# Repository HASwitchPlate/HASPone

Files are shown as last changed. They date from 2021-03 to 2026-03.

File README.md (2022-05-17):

# HA SwitchPlate HASPone

The HASPone is a DIY touchscreen controller you can mount into a [standard North American work box](https://archive.org/details/NEMA-WD-6-2016).  It connects to your home automation system over Wifi+MQTT to display useful information and to control your smart devices.  The result is an attractive and highly-customizable home controller you can build yourself!

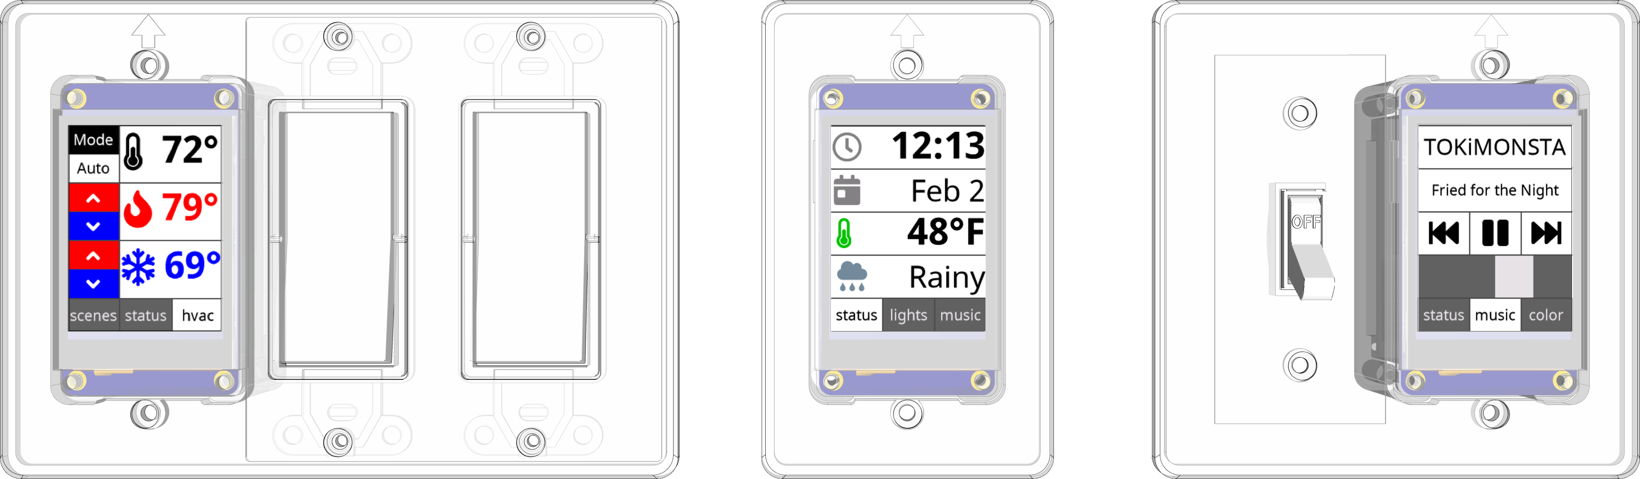
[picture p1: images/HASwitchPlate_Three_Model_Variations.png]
HA SwitchPlate Models


## Demo screens

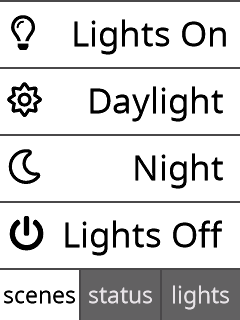
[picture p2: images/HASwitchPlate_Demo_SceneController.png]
Scene controller
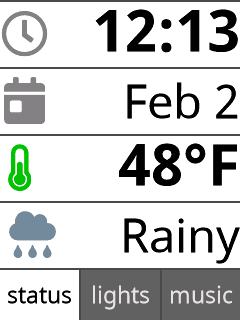
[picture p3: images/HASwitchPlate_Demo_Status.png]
Status display
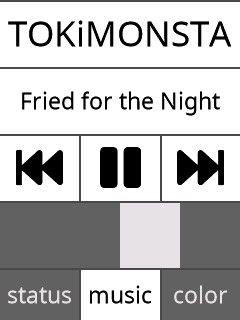
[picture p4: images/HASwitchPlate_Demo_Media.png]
Media control
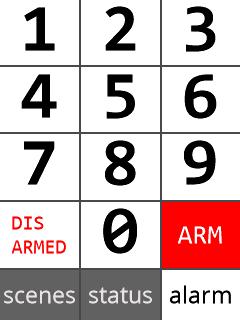
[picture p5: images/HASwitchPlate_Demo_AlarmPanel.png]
Alarm Panel
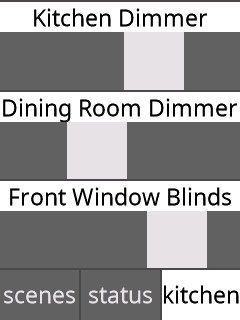
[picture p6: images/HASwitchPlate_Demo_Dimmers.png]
Slider/Dimmer Controls
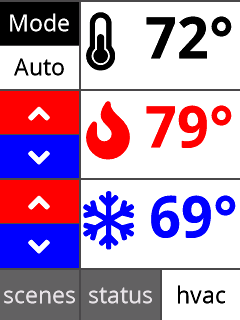
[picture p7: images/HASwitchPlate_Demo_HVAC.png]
HVAC Controls
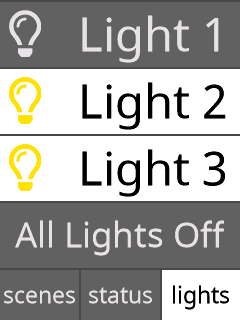
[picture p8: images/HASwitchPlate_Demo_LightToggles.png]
Light toggles
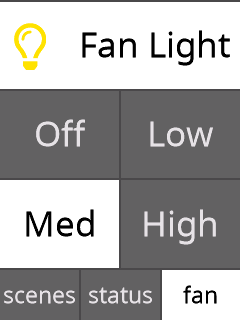
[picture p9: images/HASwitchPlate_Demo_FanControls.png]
Fan controller
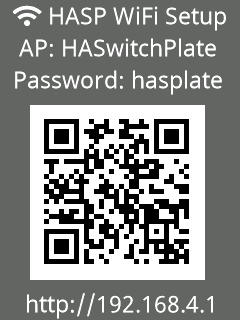
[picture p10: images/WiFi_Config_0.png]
WiFi Setup
        

## [Purchase an assembled unit](https://www.etsy.com/listing/1191709235/haspone-haswitchplate-touchscreen-home)

This build requires some specialist skills and tools. [You can buy an assembled device here](https://www.etsy.com/listing/1191709235/haspone-haswitchplate-touchscreen-home) if you want to get started without picking up a soldering iron.  [Buy the PCB here](https://www.etsy.com/listing/1177721322/haspone-pcb) if you want to safely assemble your own HASPone.

## [Build your own HASPone](https://github.com/HASwitchPlate/HASPone/wiki/Building-your-own-HASPone)

[Check out the build guide in the HASPone wiki](https://github.com/HASwitchPlate/HASPone/wiki/Building-your-own-HASPone).

## [Setup HASPone for Home Assistant](https://github.com/HASwitchPlate/HASPone/wiki/Configure-your-HASPone-for-Home-Assistant)

If you're purchased or built a HASPone, [now it's time to make it talk to Home Assistant](https://github.com/HASwitchPlate/HASPone/wiki/Configure-your-HASPone-for-Home-Assistant).

Here's a quick look at the setup process:

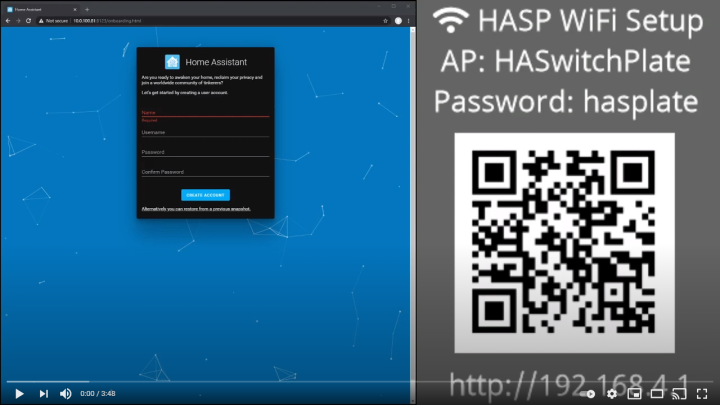
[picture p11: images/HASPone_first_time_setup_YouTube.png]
HASPone first-time setup (https://youtu.be/zi784hr69QA)


## Have a question?

Come talk to us in [the HASPone discussion forum](https://github.com/HASwitchPlate/HASPone/discussions) or [chat with us on Discord](https://haswitchplate.com/discord).

## [Buy me a coffee](https://www.buymeacoffee.com/gW5rPpsKR)

Buy me a coffee (https://www.buymeacoffee.com/gW5rPpsKR)

This project is powered by coffee.  [I might get a little weird about it at times](https://github.com/aderusha/RoastLearner), but it's not much of a stretch to suggest that coffee both powers and consumes a fair portion of my mental energy.  [Hook me up if you think HASP is cool](https://www.buymeacoffee.com/gW5rPpsKR).  Thanks!

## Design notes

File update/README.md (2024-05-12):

# HASP Auto-Update

Files here are used for the auto-update routine which will periodically check GitHub for new firmware versions.  

---

## Legacy Releases

If you need to downgrade for whatever reason, paste the link below into the "Update ESP8266 from URL" dialog under "Update Firmware".

* **HASPone 1.05** `https://raw.githubusercontent.com/HASwitchPlate/HASPone/570eefcb901c8eb40947a5fa53b8760ae21612f2/Arduino_Sketch/HASwitchPlate.ino.d1_mini.bin`
* **HASPone 1.04** `https://raw.githubusercontent.com/HASwitchPlate/HASPone/f20474d8f705f9dc08ac3c8c1d5c3de324d1e6fe/Arduino_Sketch/HASwitchPlate.ino.d1_mini.bin`
* **HASPone 1.03** `https://raw.githubusercontent.com/HASwitchPlate/HASPone/2a8df65334f8b694676e4e2d75cdc7e6daac9b4e/Arduino_Sketch/HASwitchPlate.ino.d1_mini.bin`
* **HASPone 1.02** `https://raw.githubusercontent.com/HASwitchPlate/HASPone/2098a87c3b6910992a1b425628f7b1b8735487db/Arduino_Sketch/HASwitchPlate.ino.d1_mini.bin`
* **HASPone 1.01** `https://raw.githubusercontent.com/HASwitchPlate/HASPone/a1ca2c244bc15feb0360132d86a3048908be5aa6/Arduino_Sketch/HASwitchPlate.ino.d1_mini.bin`
* **HASPone 1.00** `https://raw.githubusercontent.com/HASwitchPlate/HASPone/bdaa5e7d906666df31adba7b503f14c2e3ccaeb5/Arduino_Sketch/HASwitchPlate.ino.d1_mini.bin`

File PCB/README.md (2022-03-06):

# PCB source files and Gerber outputs

Above you'll find [KiCad](http://kicad-pcb.org/) [schematic](https://github.com/aderusha/HASwitchPlate/blob/master/PCB/HASwitchPlate.sch) and [PCB](https://github.com/aderusha/HASwitchPlate/blob/master/PCB/HASwitchPlate.kicad_pcb) files along with [a ZIP bundle containing complete gerber outputs](https://github.com/aderusha/HASwitchPlate/raw/master/PCB/HASwitchPlate.gerbers.zip) ready to send to [your favorite PCB shop](https://www.allpcb.com/?Mb_InviteId=34099).

I had these manufactured by [AllPCB](https://www.allpcb.com/?Mb_InviteId=34099) and I'm very happy with the results.  The quality has been perfect and their shipping time to the US has been under a week across several orders.  [If you sign up through this link](https://www.allpcb.com/?Mb_InviteId=34099)  they credit me some cash that I can use for future projects which helps me out a bit.

If you aren't looking to buy a zillion boards, I may have some ready for US orders in [my Etsy store](https://www.etsy.com/listing/1177721322/haspone-pcb).

HA SwitchPlate PCB

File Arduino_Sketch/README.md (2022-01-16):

# HASwitchPlate Arduino Sketch

Here you'll find the [Arduino source code](./HASwitchPlate/HASwitchPlate.ino) for the microcontroller firmware along with [a pre-compiled binary image](https://github.com/HASwitchPlate/HASPone/raw/main/Arduino_Sketch/HASwitchPlate.ino.d1_mini.bin) which can be [flashed directly to your ESP8266](https://github.com/HASwitchPlate/HASPone/wiki/Flashing-HASPone-to-an-ESP8266).

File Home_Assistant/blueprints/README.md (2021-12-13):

# HASPone Blueprint Exchange

---

## HASPone Core Functionality



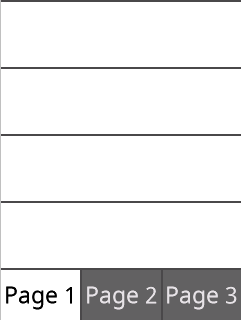
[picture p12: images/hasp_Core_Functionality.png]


This blueprint provides the basic functionality for your HASPone. Deploy one automation from this blueprint for each of your HASPone devices.

---

### Activate Page on Idle



Activates a selected page after a specified period of inactivity.

---

### Activate Page



A button on the HASPone will activate a page when pressed. Can be combined on a button with another blueprint which displays text.

---

### Create Device Triggers



Create [Device Triggers](https://www.home-assistant.io/integrations/device_trigger.mqtt/) for each of the HASPone buttons defined. Device triggers can be utilized while creating your own automations through the Home Assistant UI. This allows for the easy creation of automations which will be triggered when pressing buttons on your HASPone.

---

### Display Alarm Control on Page 7



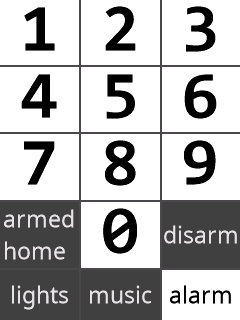
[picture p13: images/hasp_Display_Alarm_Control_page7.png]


Page 7 controls a selected alarm panel for code entry and arm/disarm.

---

### Display Calendar with Icon



Preview

A HASPone button displays month + date on the right with a calendar icon on the left.

---

### Display Clock with Icon



Preview

A HASPone button displays a clock on the right with a clock icon on the left.

---

### Display Clock



Preview

A HASPone button displays a clock with configurable text options.

---

### Display Dimmer with Icon



Preview

A HASPone button displays a dimmer control on page 4 and 5 with a toggle on/off icon to the left.

---

### Display Entity State or Attribute



Preview

A HASPone button displays the state or attribute value of an entity

---

### Display Media Controls on Page 8



Preview

Page 8 controls a selected media player with artist and track info, track back/play|pause/track forward, and volume control

---

### Display Template



Preview

A button on the HASPone will display the output of a template.  The template is updated when the state of a selected entity updates.

---

### Display Text



Preview

A button on the HASPone will display text.  This can be useful when combined with other blueprints which perform an action, but don't apply a label to a button. Deploy both blueprints on the same button, and now you have a button that says things and does things.

---

### Display Toggle



Preview

Press a button on the HASPone to toggle the state of an entity.  The button colors and text can change in response to the on/off state or attribute of the selected entity.

---

### Display Value with Icon and Colors



Preview

A HASPone button displays the current value of an entity (state or attribute) with a dynamic icon on the left and (optional) colors.  Up to 5 icons and color ranges are supported.

---

### Display Volume Control on page 8



Preview

The slider button on page 8 displays a volume control

---

### Display Weather Condition with Icon



Preview

A HASPone button displays the current weather condition on the right with a matching icon on the left

---

### Display Weather Condition Icon Only



Preview

A HASPone button displays the current weather condition as an icon

---

### Display Weather Forecast



Preview

A HASPone button displays an attribute of a selected weather forecast. You can use this to display tomorrow's condition, or tonight's low temp. Available forecast conditions will vary by weather provider, check your selected provider's state under `Developer Tools` > `States` to get a sense of what your selected provider has to offer.

---

### Display Weather Temperature with Colored Icon Only



Preview

A HASPone button displays the current temperature as an icon that is optionally coloured.

---

### Display Weather Temperature with Icon and Colors



Preview

A HASPone button displays the current temperature from a selected weather provider on the right with a dynamic thermometer icon on the left and (optional) colors.

---

### Perform Action



A button on the HASPone will perform an action when pressed. Can be combined on a button with another blueprint which displays text.

---

### Cycle Automations



Preview

A button on the HASPone will toggle through as many as 10 selected automations.  This allows the user to assign multiple blueprints to the same button on the HASPone device, and to cycle between them by pressing the selected button.

Optionally, a timeout can be set to cycle back to a "default" automation after a specified interval, or to continuously cycle through selected automations.

---

### Dim Screen with Sun



Dim the HASPone backlight in response to the sun going up and down.

---

### Dim Screen on Idle



Dim the screen backlight after a specified period of inactivity.

---

### Apply Theme



A button on the HASPone will have the current device theme or custom colors applied.

---

### HASPone Theme Dark on Light



Preview

Press RUN ACTIONS to apply the theme Dark on Light to the selected HASPone device

---

### HASPone Theme Light on Dark



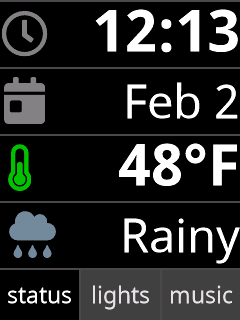
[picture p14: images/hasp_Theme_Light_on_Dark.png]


Press RUN ACTIONS to apply the theme Light on Dark to the selected HASPone device

---

### HASPone Theme Light on Dark Blue



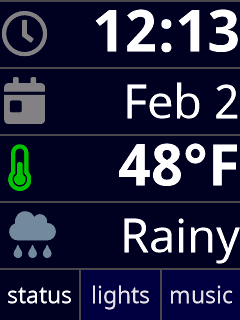
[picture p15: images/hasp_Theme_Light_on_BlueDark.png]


Press RUN ACTIONS to apply the theme Light on Dark Blue to the selected HASPone device

---

### Remove MQTT Discovery Devices



Press RUN ACTIONS to remove retained MQTT discovery messages for a decommissioned HASPone.

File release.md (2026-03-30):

# HASPone v1.09 Release Notes

## Home Assistant Update Integration

HASPone now registers as an updatable device in Home Assistant. When a firmware update is available, it appears in the HA **Settings > Updates** dashboard alongside your other device updates.

- **ESP8266 firmware** and **Nextion LCD firmware** are tracked as separate update entities
- Click **Install** directly from Home Assistant to trigger the OTA update
- Release notes link is included in each update card, configurable per-release via `version.json`
- Update availability is checked automatically every 12 hours

## Fix for breaking changes in Home Assistant MQTT entity naming

Big thanks to @SylvainGa for the 1.07 and 1.08 releases, fixing a breaking change in Home Assistant: https://github.com/HASwitchPlate/HASPone/commit/68df52da6bd4ba3a4f2c9e98dcf1b7bcd363443b

**All blueprints will need to be updated!** - make sure to copy down all files from `Home_Assistant/blueprints/*.yaml` into your Home Assistant installation.

## Bug Fixes

### Fixed Nextion ACK timeout logic

The ACK wait loops in `nextionSetAttr()` and `nextionGetAttr()` used `||` (OR) with an inverted timeout comparison, meaning they would exit immediately instead of waiting for the ACK response. Changed to `&&` (AND) with corrected comparison direction so the loop properly waits for either an ACK or a timeout.

### Fixed beep on/off state inversion

The beep feedback had on and off states swapped: `analogWrite(beepPin, 254)` was called during the "off" phase and `analogWrite(beepPin, 0)` during the "on" phase. Corrected so the beep actually sounds during the on interval.

### Fixed WiFi password display in web UI

The web configuration page checked `mqttUser` instead of `mqttPassword` when deciding whether to show the password placeholder. The MQTT password field would appear empty even when a password was saved.

### Fixed page restore after LCD reboot

`nextionReset()` and `espWifiConnect()` compared `nextionActivePage` with a truthy check, which treated page 0 as "no page set." Changed to `>= 0` so page 0 is correctly restored.

### Fixed debugPrint() brace scoping

`debugPrint()` had a misplaced opening brace that put `Serial.print(debugText)` outside the `if (debugSerialEnabled)` block, causing serial output even when debug was disabled.

## Improvements

### mDNS actually starts now

Added the missing `MDNS.begin(haspNode)` call. Without it, the mDNS service registration was configured but the responder itself was never started, so the device was not discoverable on the local network.

### mDNS now advertises MAC address and MQTT server

Added `mac` and `mqtt_server` TXT records to the mDNS service advertisement, making device identification easier on the local network.

### WiFi reconnection hardened

- `WiFi.hostname()`, `WiFi.setAutoReconnect(true)`, and `WiFi.setSleepMode(WIFI_NONE_SLEEP)` are now set on both initial connection and reconnection
- `espWifiReconnect()` uses saved credentials from WiFiManager when no hardcoded SSID is configured, instead of passing empty strings to `WiFi.begin()`
- WiFi persistence disabled during reconnection to avoid unnecessary flash writes
- All WiFi settings are reapplied after reconnection

### OTA update reliability improved

- MQTT client, TLS buffers, telnet, and web server are disconnected/stopped before starting ESP OTA to free memory
- HTTPS OTA buffer increased from 512 to 4096 bytes for more reliable downloads
- Removed manual URL parsing — `ESPhttpUpdate` handles it with `HTTPC_FORCE_FOLLOW_REDIRECTS`

### Update check rewritten for Cloudflare compatibility

`updateCheck()` was rewritten to use raw HTTP/1.0 requests with explicit content-length parsing instead of `HTTPClient`. This resolves failures when `version.json` is served behind Cloudflare's edge network.

### Firmware download URLs switched to HTTP

Default firmware URLs changed from `https://` to `http://` to reduce memory pressure during OTA downloads on the ESP8266. Previously HTTPS was used through a cloud-hosted VM which would proxy from GitHub, that now runs through CloudFlare.  While this does change from HTTPS to HTTP, the security posture doesn't change as the ESP8266 does not have the capacity to pull in and validate the full cert chain so it never did actually check any part of that in previous releases.  The update check itself still uses HTTPS.

### Debug serial output optimized

`SoftwareSerial debugSerial` is now a global instance instead of being constructed and destroyed on every `debugPrintln()` / `debugPrint()` / `debugPrintCrash()` call. Reduces heap churn during debug output.

### OTA progress display deduplicated

`nextionUpdateProgress()` now only sends display updates when the percentage actually changes, avoiding redundant serial commands to the Nextion during firmware uploads.

### PlatformIO build configuration updated

Added `monitor_speed = 115200` and `upload_speed = 921600` to `platformio.ini` for faster development iteration.

## ESPHome Example Updated

The ESPHome example configuration (`esphome/haspone.yaml`) has been updated with:

- Serial logging disabled (`baud_rate: 0`) since the UART pins conflict with the Nextion — logs are available via the web UI and ESPHome dashboard instead
- Updated `ota:` to current ESPHome syntax (`platform: esphome`)
- Detailed header comments explaining the hardware UART constraints and why SoftwareSerial is required on this PCB
- Version bumped to 0.0.2

## version.json Changes

All firmware entries now include a `release_url` field pointing to the GitHub releases page. The device reads this on each update check and passes it to Home Assistant so the update card links to the correct release notes.

## Files Changed

| File | Description |
|---|---|
| `Home_Assistant/blueprints/*.yaml` | New blueprints as of v1.08 for breaking changes in Home Assistant |
| `Arduino_Sketch/HASwitchPlate/HASwitchPlate.cpp` | All firmware changes above |
| `Arduino_Sketch/HASwitchPlate.ino.d1_mini.bin` | Compiled firmware binary |
| `Arduino_Sketch/debug/HASwitchPlate.ino.d1_mini.elf` | Debug symbols |
| `Arduino_Sketch/platformio.ini` | Build config updates |
| `esphome/haspone.yaml` | ESPHome example improvements |
| `update/version.json` | Updated paths, added release_url |

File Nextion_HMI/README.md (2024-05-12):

# Nextion HMI

The Nextion panel ships with a default demo configuration which we need to overwrite with the included compiled code.  The file [HASwitchPlate.tft](HASwitchPlate.tft) can be saved to a FAT32-formatted microSD card and placed into the panel before power on.  The panel will recognize the code update and load it automatically, after which you're ready to connect to the microcontroller.  Note that some users have reported problems with cards formatted under Linux, so use a Windows system for this process and it should work without trouble.

If you want to manually edit your own panels, [download the editor from Nextion](https://nextion.itead.cc/resource/download/nextion-editor/) and you can flash the panel directly via serial.

Please [check the Nextion HMI documentation](../Documentation/02_Nextion_HMI.md) for additional details.

## Nextion Files Explained

* **[HASwitchPlate.hmi](HASwitchPlate.hmi)** This is the "source" file which you can modify in the [Nextion editor](https://nextion.itead.cc/resource/download/nextion-editor/).  If you want to make your own Nextion HMI, I'd recommend starting with this file, keeping Page 0 (`p0`), then start your own design on pages 1+.
* **[HASwitchPlate.tft](HASwitchPlate.tft)** This is the compiled Nextion firmware for the HASPone usable on a Basic series Nextion 2.4" LCD, model `NX3224T024_011R`
* **[HASwitchPlate-Inverted.tft](HASwitchPlate-Inverted.tft)** Basic series firmware but inverted, usable if the viewing angle on your display works better when mounted upside-down.
* **[HASwitchPlate-Discovery.tft](HASwitchPlate-Discovery.tft)** This is the compiled Nextion firmware for the HASPone usable on a Discovery series Nextion 2.4" LCD, model `NX3224F024_011R`.  This is a drop-in replacement for the Basic series, might be cheaper or more readily available than the Basic, and is fully supported by the HASPone project.
* **[HASwitchPlate-Discovery-Inverted.tft](HASwitchPlate-Discovery-Inverted.tft)** Discovery series firmware but inverted, usable if the viewing angle on your display works better when mounted upside-down.
* **[HASwitchPlate-Enhanced.tft](HASwitchPlate-Enhanced.tft)** This is the compiled Nextion firmware for the HASPone usable on an enhanced Nextion 2.4" LCD, model `NX4024K032_011R`.  This panel will not fit in the provided 3D printed enclosure and no enhanced features are used in this project.  **Don't buy this panel**, but if you did (*and you shouldn't*), you can use this firmware.
* **[HASwitchPlate-TJC.hmi](HASwitchPlate-TJC.hmi)** This is the "source" file for the Chinese-market TJC LCD model `TJC3224T024_011`.  This file cannot be used with the english language editor.  If you purchase this panel, you will need to use the Chinese-language "USART HMI" editor to modify this file.  **Don't buy this panel**.
* **[HASwitchPlate-TJC.tft](HASwitchPlate-TJC.tft)** This is the compiled Nextion firmware for the HASPone usable on a Chinese market TJC 2.4" LCD, model `TJC3224T024_011`.

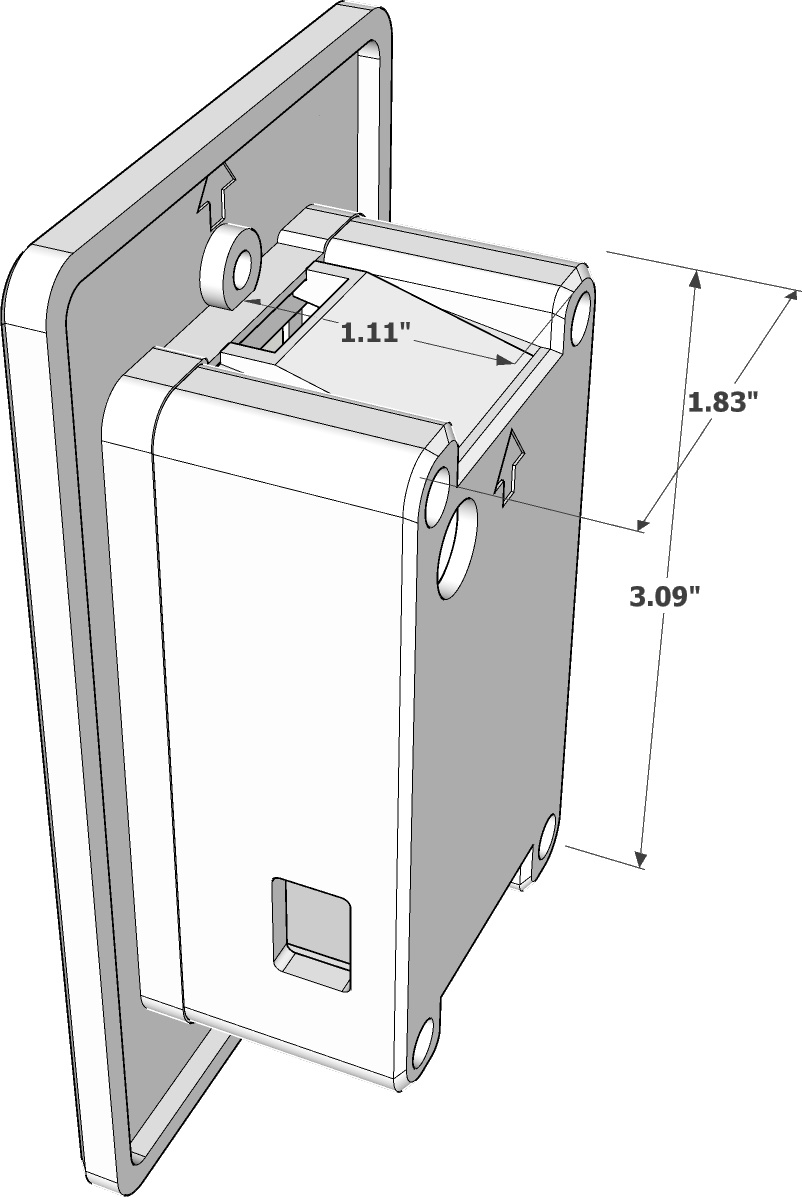
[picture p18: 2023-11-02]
images/HASwitchPlate_rear_box_dimensions.jpg

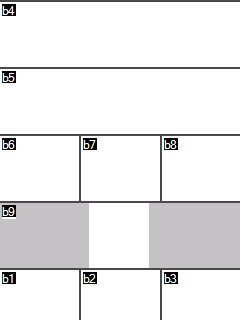
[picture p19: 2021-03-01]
images/NextionUI_p8_5buttons+1slider.png

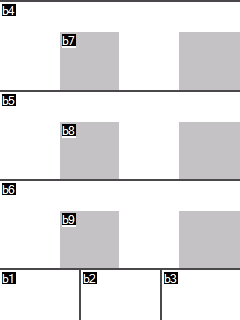
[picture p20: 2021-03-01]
images/NextionUI_p4-p5_3sliders.png

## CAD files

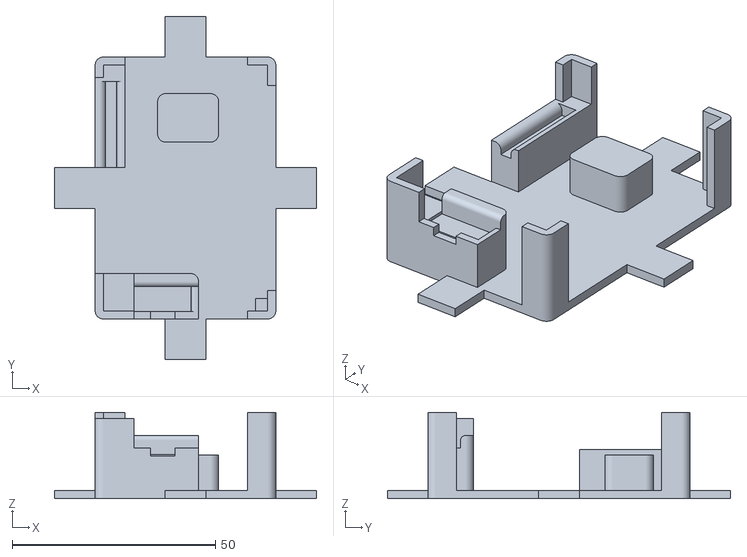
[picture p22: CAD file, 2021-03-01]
3D_Printable_Models/HASwitchPlate_assembly_jig.stl
64.4 x 84.4 x 21.2

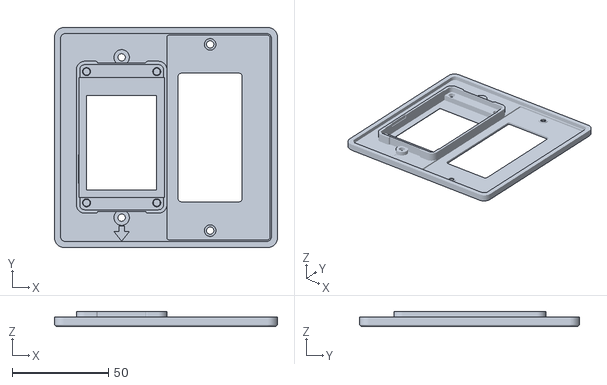
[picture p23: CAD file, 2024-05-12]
3D_Printable_Models/HASwitchPlate_front_2x_hasp_decora.stl
115.9 x 114.3 x 8.00

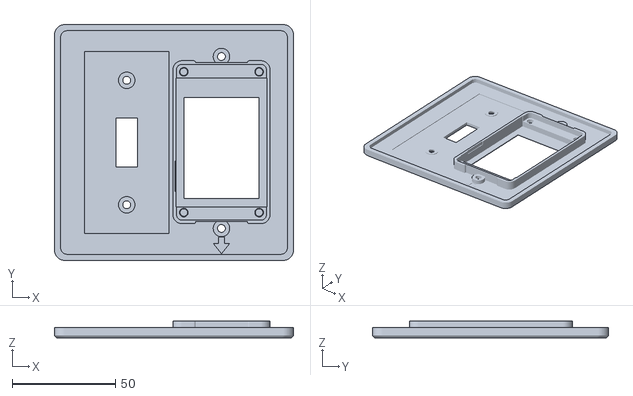
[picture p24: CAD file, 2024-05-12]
3D_Printable_Models/HASwitchPlate_front_2x_toggle_hasp.stl
115.8 x 114.3 x 8.00

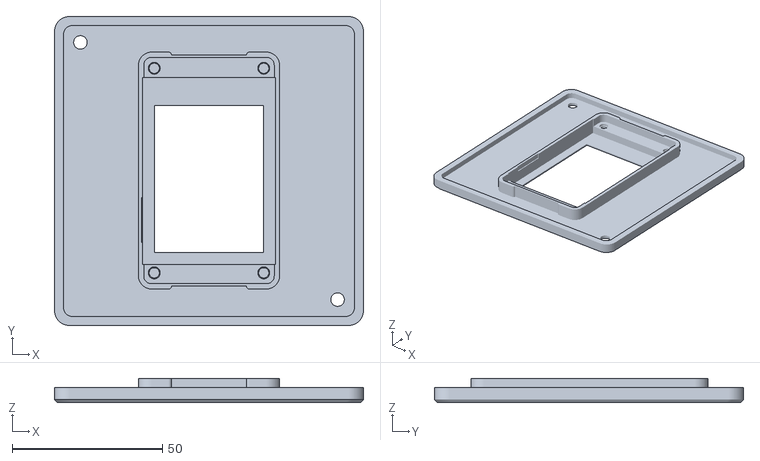
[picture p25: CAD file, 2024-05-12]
3D_Printable_Models/HASwitchPlate_front_4in_box.stl
103.0 x 103.0 x 8.00

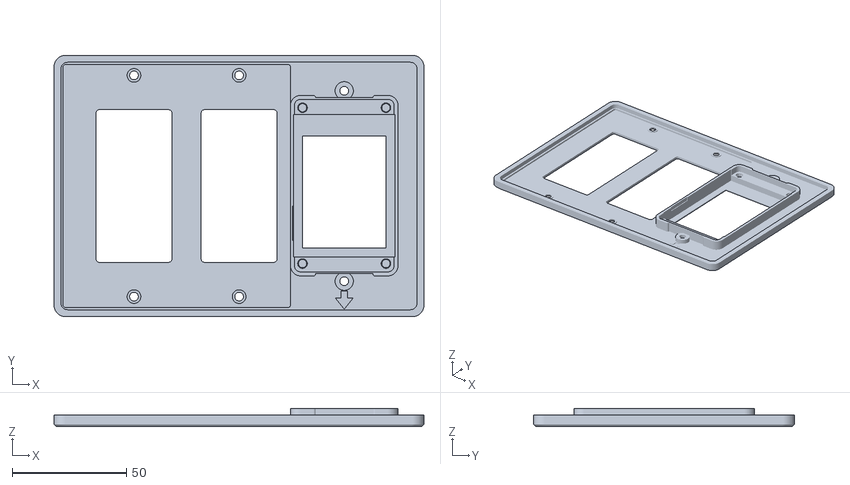
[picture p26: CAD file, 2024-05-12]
3D_Printable_Models/HASwitchPlate_front_3x_decora_decora_hasp.stl
161.9 x 114.3 x 8.00

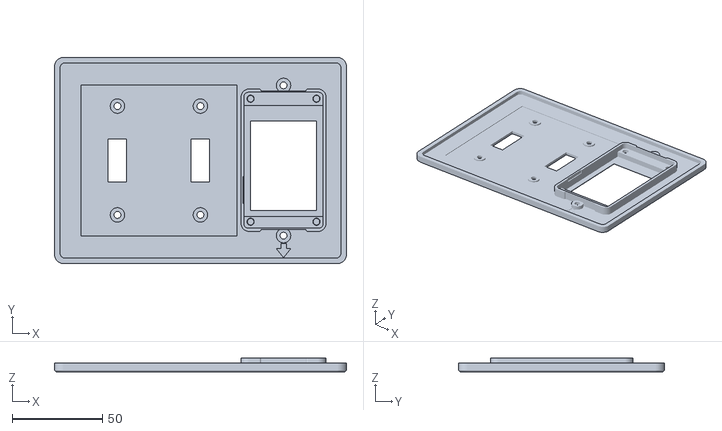
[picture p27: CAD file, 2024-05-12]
3D_Printable_Models/HASwitchPlate_front_3x_toggle_toggle_hasp.stl
161.9 x 114.3 x 8.00

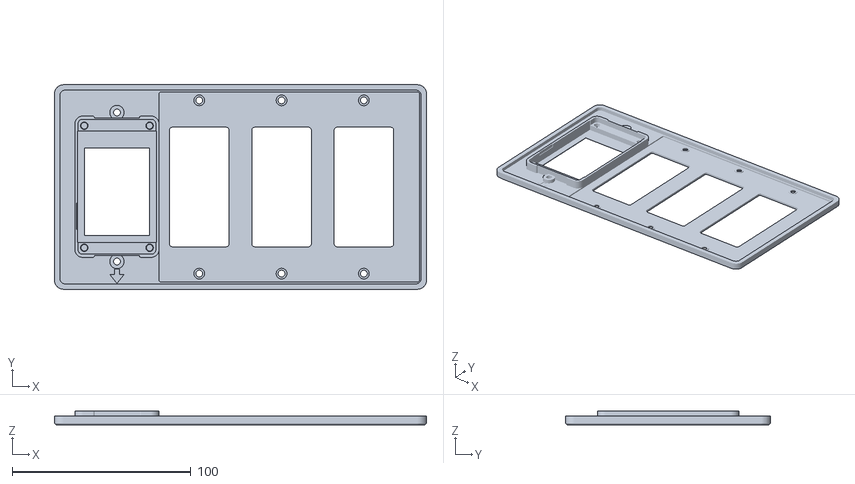
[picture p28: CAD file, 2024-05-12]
3D_Printable_Models/HASwitchPlate_front_4x_hasp_decora_decora_decora.stl
207.9 x 114.3 x 8.00

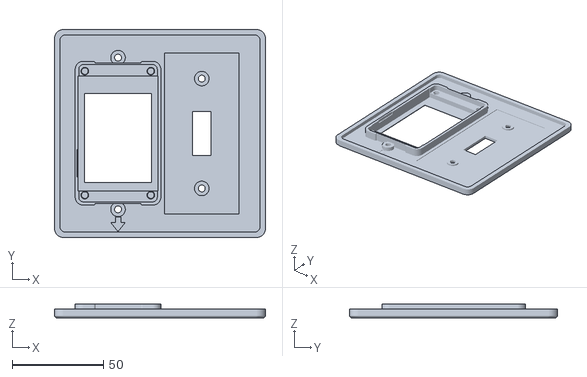
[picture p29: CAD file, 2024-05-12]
3D_Printable_Models/HASwitchPlate_front_2x_hasp_toggle.stl
115.9 x 114.3 x 7.70

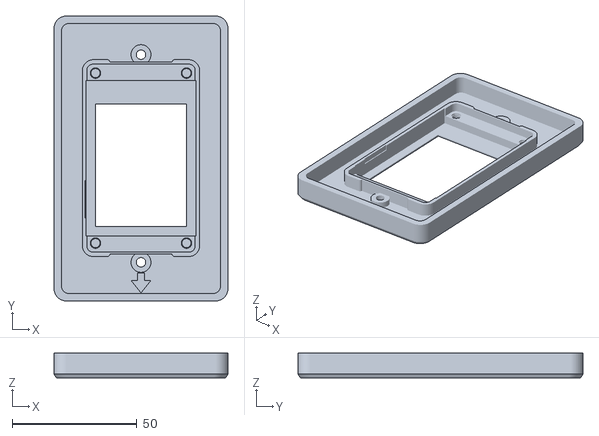
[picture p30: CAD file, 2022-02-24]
3D_Printable_Models/HASwitchPlate_front_single_deep.stl
69.8 x 114.3 x 10.00

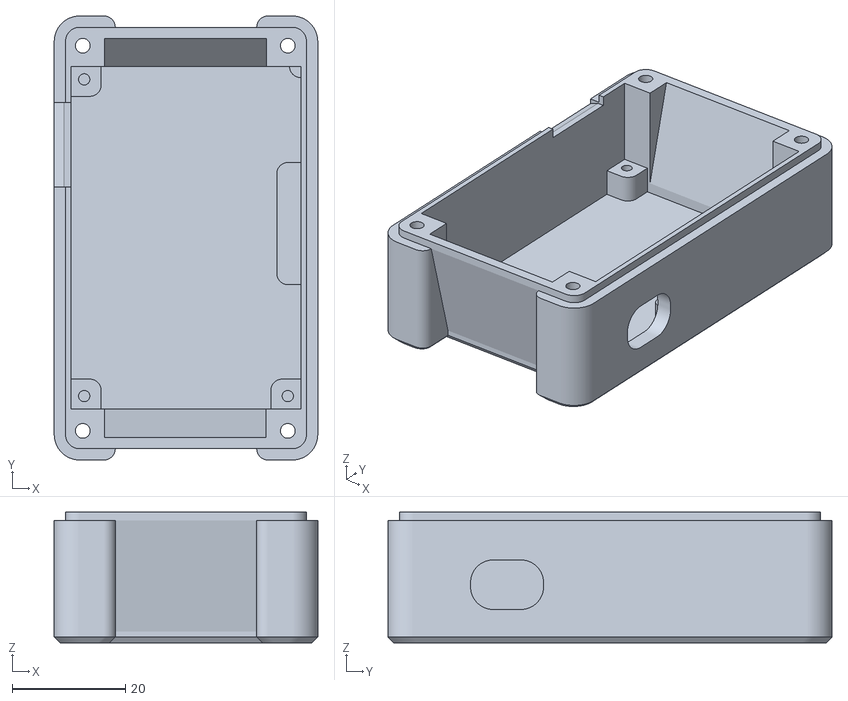
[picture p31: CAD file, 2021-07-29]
3D_Printable_Models/HASwitchPlate_desktop_rear_enclosed.stl
46.6 x 78.5 x 23.1

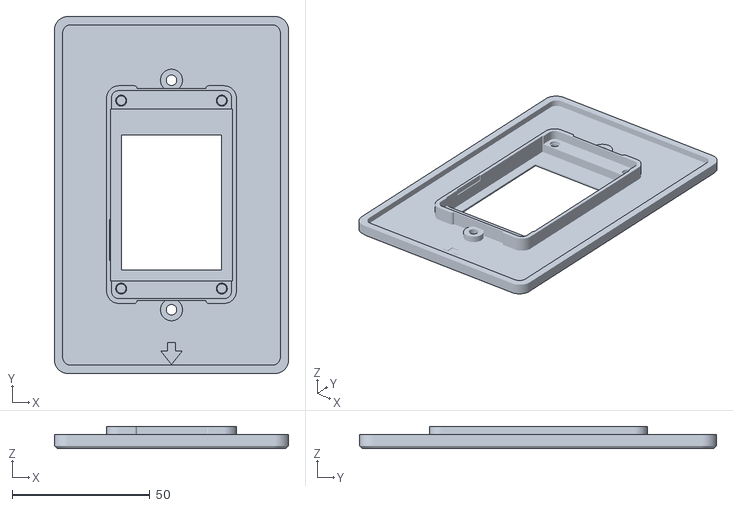
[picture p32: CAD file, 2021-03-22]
3D_Printable_Models/HASwitchPlate_front_single_large.stl
85.0 x 129.5 x 8.00

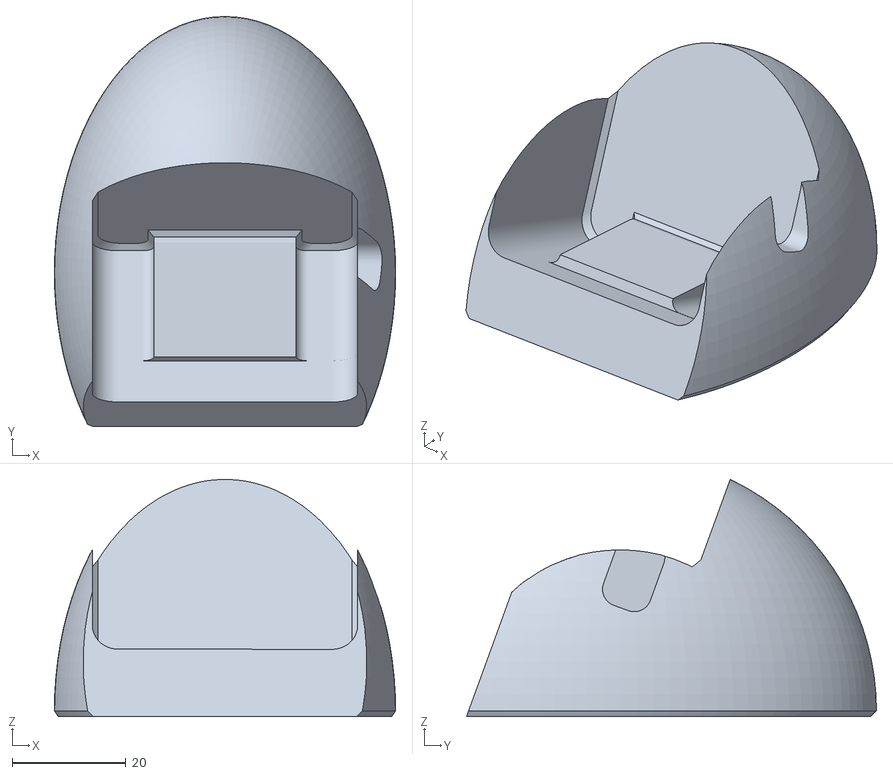
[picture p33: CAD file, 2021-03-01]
3D_Printable_Models/HASwitchPlate_desktop_minibase.stl
59.9 x 72.0 x 41.6

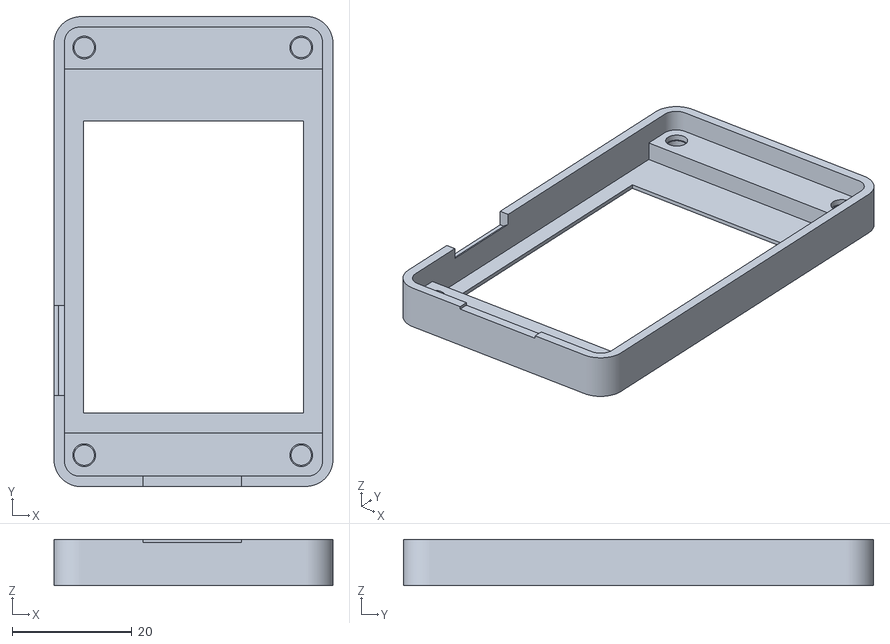
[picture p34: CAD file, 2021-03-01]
3D_Printable_Models/HASwitchPlate_desktop_front.stl
46.6 x 78.5 x 7.70

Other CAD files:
3D_Printable_Models/HASwitchPlate_front_3x_hasp_decora_decora.stl
3D_Printable_Models/HASwitchPlate_front_2x_decora_hasp.stl
3D_Printable_Models/HASwitchPlate_front_3x_decora_hasp_decora.stl
3D_Printable_Models/HASwitchPlate_front_3x_hasp_toggle_toggle.stl
3D_Printable_Models/HASwitchPlate_desktop_rear.stl
3D_Printable_Models/HASwitchPlate_desktop_base.stl
3D_Printable_Models/HASwitchPlate_front_4x_decora_hasp_decora_decora.stl
3D_Printable_Models/HASwitchPlate_front_5x_decora_decora_hasp_decora_decora.stl
3D_Printable_Models/HASwitchPlate_front_single.stl
3D_Printable_Models/HASwitchPlate_front_single_UK-UNTESTED.stl
3D_Printable_Models/HASwitchPlate_front_single_dev.stl
3D_Printable_Models/HASwitchPlate_rear_dev.stl
3D_Printable_Models/HASwitchPlate_rear_lcdmod.stl
3D_Printable_Models/HASwitchPlate_rear_lcdmod_minimum_clearance.stl
3D_Printable_Models/HASwitchPlate_rear_nolcdmod.stl

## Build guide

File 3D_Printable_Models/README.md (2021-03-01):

# Switch Plate model for single-gang workbox

## 3D Printed Enclosure

Above you'll find STL files ready for slicing and the source models editable in the free edition of [SketchUp Make](https://www.sketchup.com/download).  There are several models presented here for various plate configurations on the front and two options for the rear enclosure.

For most users, you'll want to print [HASwitchPlate_front_single.stl](HASwitchPlate_front_single.stl) and [HASwitchPlate_rear_nolcdmod.stl](HASwitchPlate_rear_nolcdmod.stl).

### Front plate models

* **[HASwitchPlate_front_single.stl](HASwitchPlate_front_single.stl)** Standard single-wide plate. `[HASP]`
* **[HASwitchPlate_front_2x_hasp_decora.stl](HASwitchPlate_front_2x_hasp_decora.stl)** Double-wide plate with Decora switch to the right `[HASP|Decora]`
* **[HASwitchPlate_front_2x_hasp_toggle.stl](HASwitchPlate_front_2x_hasp_toggle.stl)** Double-wide plate with toggle switch to the right `[HASP|toggle]`
* **[HASwitchPlate_front_3x_hasp_decora_decora.stl](HASwitchPlate_front_3x_hasp_decora_decora.stl)** Triple-wide plate with Decora switches to the right `[HASP|Decora|Decora]`
* **[HASwitchPlate_front_3x_hasp_toggle_toggle.stl](HASwitchPlate_front_3x_hasp_toggle_toggle.stl)** Triple-wide plate with toggle switches to the right `[HASP|toggle|toggle]`
* **[HASwitchPlate_front_5x_decora_decora_hasp_decora_decora.stl](HASwitchPlate_front_5x_decora_decora_hasp_decora_decora.stl)** 5-wide plate with 4x Decora switches and HASP in center `[Decora|Decora|HASP|Decora|Decora]`
* **[HASwitchPlate_front_single_dev.stl](HASwitchPlate_front_single_dev.stl)** Standard single-wide plate with SD card exposed for development use (unsafe!) `[HASP]`

### Rear enclosure models

* **[HASwitchPlate_rear_lcdmod.stl](HASwitchPlate_rear_lcdmod.stl)** The `lcdmod` enclosure requires the removal of the 4-pin XHP connector from the Nextion LCD panel.  This option allows for better clearance around the screw posts which may help in tight work boxes, but the process of safely removing the connecter may require a hot air station.
* **[HASwitchPlate_rear_nolcdmod.stl](HASwitchPlate_rear_nolcdmod.stl)** The `nolcdmod` enclosure does not require removing the 4-pin XHP connector from the Nextion LCD panel.  This simplifies the build process but has just a little less room behind the device for the work box screws.  We're not talking a lot here, so if you don't have the hot air station this option will probably work fine for you.
* **[HASwitchPlate_rear_lcdmod_minimum_clearance.stl](HASwitchPlate_rear_lcdmod_minimum_clearance.stl)** The `lcdmod_minimum_clearance` rear enclosure has been modified to provide the tightest fit around the HASP components that I can work out.  The walls are flimsy and thin, it will require supports to print, and you'll need 4 x [4mm M2 countersunk screws](https://amzn.to/2Eaz9wl) to assemble.  I don't recommend this enclosure unless you can't get the standard enclosure to fit in your workbox.
* **[HASwitchPlate_rear_dev.stl](HASwitchPlate_rear_dev.stl)** The `dev` enclosure has USB, SD card, and Nextion XHP connector exposed for development/test purposes.  This is unsafe to install in your workbox.

### Desktop models

An enclosure designed for desktop (table, bedstand, etc) use has been developed.  The enclosure will fit the standard PCB, WeMos D1 Mini, and Nextion 2.4" but will not allow installation or use of the AC PSU.  Power is provided by USB connection to the WeMos D1 Mini.

* **[HASwitchPlate_desktop_front.stl](HASwitchPlate_desktop_front.stl)** Front panel for desktop use with opening for SD card access
* **[HASwitchPlate_desktop_rear.stl](HASwitchPlate_desktop_rear.stl)** Rear enclosure for desktop use with openings for SD card, USB, and Nextion Serial access
* **[HASwitchPlate_desktop_base.stl](HASwitchPlate_desktop_base.stl)** Handy base for desktop use.  Print with higher infill to add mass to weigh it down a bit.

## 3D Printing Notes

### FDM affordance

The careful observer might note that the dimensions of the model vary just slightly from the [published dimensions](https://www.itead.cc/wiki/images/a/ad/2.4%27%27_Nextion_Dimension.pdf) of the panel used in this project.  This has been done to accommodate the nature of FDM 3D printing, which means that other production technologies may require slight modifications to make everything fit snug.  The STLs are published in the correct orientation for printing.

### Filament

I printed these two parts with [AmazonBasics White PETG](https://amzn.to/2I6ctPd) on a [Prusa i3 MK3](https://shop.prusa3d.com/en/3d-printers/180-original-prusa-i3-mk3-kit.html) with 20% infill, .15mm layers, no supports, and 6 bottom layers.  PETG provides good flexibility when mounting the device into your wall, as sometimes the drywall, workbox, etc require a little bit of flex.  PLA might work, but may crack in some installations.  If you have both on hand, print the front in PETG and the back in PLA.

### Inserts

The mounting holes for the Nextion panel are sized to fit [M2 x 3mm threaded inserts](https://amzn.to/2N511Fh) but should accept an M3 screw (tightly).  See [the enclosure build documentation](../Documentation/04_Project_Enclosure.md#threaded-inserts) for more details.

### SketchUp

The SketchUp file included here is dimensioned in meters but 1m == 1mm due to issues with how SketchUp (doesn't) handle small dimensions.  If you intend to modify the provided SketchUp model, export to STL in meters then import for print in mm (the standard setting for most slicers) and you'll be fine.  The included STLs are ready to slice as-is.

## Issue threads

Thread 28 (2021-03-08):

HASPone Overlay Issues

IIAIronWolf, 2021-03-08:
Reference discussion: #20
Including what is mentioned in the above discussion, I have also noticed the page buttons stay white (as if they are active, unlike their normal grey, inactive state). This happens every now and then and required pressing different page buttons a few times until things go back to normal.
Can provide more info if necessary.

aderusha, 2021-03-08:
Can you explain the sequence of events you see?  The OP in the previous thread was dealing with the activate page blueprint, which you said you aren’t using.  What happens in your case?  What actions are you taking, and what happens in response?

IIAIronWolf, 2021-03-08:
> I am actually seeing the exact same issue as the OP on occasion, with the sticking icons, sometimes being the temperature icon. I am not using a activate page blueprint. I simply added the four blueprints you made in order to recreate the status page you had before HASPone, including date, time, temp, and weather condition. Therefore, either those blueprints have this same issue, or the Core Functionality blueprint may also need to be updated.
> In addition, and as you mentioned in this first comment, the page buttons sometimes stick in the 'activated' color, but those were only setup by core functionality on my device. I have not customized page buttons; therefore I believe this issue exists in the core functionality as well.

aderusha, 2021-03-08:
OK trying to get the exact sequence of events straight, so bear with me.

* You are starting on a page, I’ll call it page 1
* One page 1 is one or more blueprints which make use of the icon overlay
* You change pages using the center button of the three buttons on the bottom (b[2]),  which was set to go to page 2.
* Page 2 appears, blueprints assigned to this page appear, but with one or more icons from page 1 laid on top.

How am I doing?  Sound about right?

IIAIronWolf, 2021-03-08:
That is correct. That does happen sometimes.
However, more often I am seeing this:

- Start on page one
- Click to page two
- Page one button (b[1]) is still highlighted white as if it is the active page.
- Click between pages until only one button is correctly showing highlighted as the active page.

aderusha, 2021-03-08:
Allright, sounds like two separate issues going on here so I don't want to conflate the two.  I'll start with the icons.  Any chance you can [grab a debug log](https://github.com/HASwitchPlate/HASPone/wiki/Capture-HASPone-debug-output) of the problem happening?

IIAIronWolf, 2021-03-09:
I rarely see the icon overlay issue anymore with HASPone; however I may be able to get your a debug log of the button active overlay issue.

aderusha, 2021-03-29:
Any updates on this issue?  Are you still experiencing the problem?

IIAIronWolf, 2021-04-28:
I've wiped out everything as of now. Sorry for the delayed response. For now, with my better understanding of how this works, I don't believe I am seeing the issue. I will reopen it if it occurs again.

Closed 2021-04-28.

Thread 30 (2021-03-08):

HA with 6pcs HASPOne is very very slowly

proasnet, 2021-03-08:
Hi, today I configured 6pcs of HASPOne, each witch 24 automations.
Now is WebUI of HA very very slowly. If is core slowly for running automations in house, I dont know, I will know after Sunset.
And a GUI of each HASPone is very slowly, I see it with page scrolling and re-drawing texts.
Before this update, all hasps was quick :(
Is it normaly?

I am running it on RPI as HASSIO standard install.

aderusha, 2021-03-08:
Are all automations running slowly?  Or just HASP-related automations?  The rPi is a good starting point for Home Assistant but the performance is pretty low, particularly in regards to storage.  What rPi hardware are you using (pi3? or if 4, which model?), and what are you using for storage on that?

proasnet, 2021-03-09:
I am using RPI3 B+
After one day I find, that only HASP automations working slowly. Reaction of touch on any Hasp is a long, and listing of pages is too long.
As storage is only SD card in RPI with HA image 64bit, not any other storage.

aderusha, 2021-03-09:
[You might find this discussion helpful](https://old.reddit.com/r/homeassistant/comments/jvwtv1/friendly_reminder_dont_use_a_sd_card_on_a_pi/).  HASP fundamentally relies on Home Assistant automations, so if Home Assistant is running slow then HASP is going to be slow.  The linked thread is concerned with SD failures over their lifetime, but the same tips for minimizing writes to avoid killing your SD card also apply to increasing performance overall.  Disabling recorder and logger may make an impact for you.

The final suggestion in that post is what I'd generally recommend: buy a old Dell desktop off of eBay for not much money and Home Assistant will run like a champ.

proasnet, 2021-03-09:
I tried running HA on Synology NAS, before addon exist. Now, they have an Addon HA. I had HA as virtual machine, working good. Only one problem was a energy power of NAS 24/7, about 50 Watts with 5 HDDs.
Now I am powering NAS only if I need access to my files.
CPU performance of NAS was very high, so energy power too :)

aderusha, 2021-04-02:
Any update on this?  Has the suggestion above made any impact in performance?

proasnet, 2021-04-04:
Hello. Thank you for interesting. Performance is still very low. I tried
run HA on Synoligy NAS, that has better power than RPI but with no effect
to HASP speed. Problem is only with listing between pages. Reaction to call
scenes is instant and quick. There is no problem. Problem is with quick
loading of the items on any other pages. My wifi network is working perfect
with microtik devices and I have multiple APs in my house. Fixed channels
1, 6, 11 and diferent SSIDs.

Dne pá 2. 4. 2021 21:43 uživatel Allen Derusha ***@***.***>
napsal:

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

aderusha, 2021-04-04:
Allright, so I think our next step is to figure out where things are moving slowly.  Can you [post a debug log](https://github.com/HASwitchPlate/HASPone/wiki/Capture-HASPone-debug-output) of page change process?  Looking for the whole conversation, from page select button press to the page being completely loaded.  If that looks good, then the next step will be to capture the MQTT traffic with timestamps.

proasnet, 2021-04-06:
Okay. As soon as possible I will write here logs from telnet and MQTT. Now, I am searching how I can get mqtt capture with timestamps from eclipse mosquitto, that run on my HA. I am still dont know how. I have only basic log in mqtt server.

aderusha, 2021-04-06:
If you have the mosquitto command line clients installed (`sudo apt-get install mosquitto-clients`), the following command will allow you to view messages with some debug info including timestamps.  Change the first few lines to match your environment.

```bash
MQTT_BROKER=hassio.local
MQTT_USER=hassio
MQTT_PASS=hassio
mosquitto_sub -h $MQTT_BROKER -u $MQTT_USER -P $MQTT_PASS -F "[\e[36m@x \e[96m@X.@N\e[39m] [\e[94mr%r:l%l\e[39m]\t\e[0m%t\t\e[1m%p\e[0m" -t "#"
```

proasnet, 2021-04-08:
Hello @aderusha . Now I am trying install mqtt command line clients, but in a terminal I get this message:
bash: sudo: command not found

I have Home Assistant as Hassio, standard instalation, not in a raspbian etc..
Please note that I am a beginner with HA, I am a programmer for industrial automation and I am an electronic engineer

proasnet, 2021-04-15:
I am sorry for open issue. Issue is still realy, next page on all HASPs is displayed after about 5 sec after pressing next button, but now I have not a free time for testing, I am working on long project in my work. For now, I am closing this, and I will open it later.
Thank you very much.

Closed 2021-04-15.

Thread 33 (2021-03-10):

Iddle not working

proasnet, 2021-03-10:
Hi, my next problem is, that iddle blueprint not working on all HASPOne devices.
I have a scorlling page in basic for all, as 1 page as basic. In Iddle, I have a page 1 after 30 sec.
Not working.
Thank you for help.

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

aderusha, 2021-03-11:
Any chance you can post a debug log showing the behavior?

proasnet, 2021-03-12:
You mean a telnet log from any hasp? Or from?

Dne čt 11. 3. 2021 16:14 uživatel Allen Derusha ***@***.***>
napsal:

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

jhhernan, 2021-03-14:
@aderusha I think that is a typo. Check the quotation mark at the end of line 127 in the hasp_Activate_Page_on_Idle.yaml file.

aderusha, 2021-03-14:
Well that's a dumb bug, I think you nailed it @jhhernan !  Just fixed the blueprint, re-import and you should be ready to go @proasnet !

jhhernan, 2021-03-14:
Thanks @aderusha . I don't know where to comment this, so excuse me. Please check the font size of the hasp_Display_Calendar_with_Icon.yaml (line 138). Using font size 9 the text overlays with the icon.

aderusha, 2021-03-14:
Another great catch @jhhernan!  I'll get it sorted out.

I think you'll find [the Discussions link above](https://github.com/HASwitchPlate/HASPone/discussions) is a good place for comments in general.

jhhernan, 2021-03-15:
I having some trouble with this automation. It is working as expected, but it continues refreshing/"repainting" the selected page every period of inactivity. What can I check?

aderusha, 2021-03-15:
The best way to help would be to provide [a debug log of the thing happening](https://github.com/HASwitchPlate/HASPone/wiki/Capture-HASPone-debug-output).

jhhernan, 2021-03-15:
> The best way to help would be to provide [a debug log of the thing happening](https://github.com/HASwitchPlate/HASPone/wiki/Capture-HASPone-debug-output).

> I having some trouble with this automation. It is working as expected, but it continues refreshing/"repainting" the selected page every period of inactivity. What can I check?

Right now it is working perfectly. If I catch that behavior again I will attach the log. Thanks!

jhhernan, 2021-03-16:
Please let me know if this are the logs that you need.
https://gist.github.com/jhhernan/01663bc767ec82b63bd5fd25c059126a
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

proasnet, 2021-03-17:
Yesterday I deleted old blueprint and new load a blueprint. Working as description, but every period is a display refreshed. See as display flash, It's not pleasant..
Do it all HASPOne in my home.

aderusha, 2021-03-17:
Trying a different approach here, just pushed a new update to the blueprint that I think should resolve this problem (and another that I just noticed where the page change wasn't set to be retained)

aderusha, 2021-03-29:
@proasnet how are things looking on this problem?  Did the blueprint fixes resolve your issue?

proasnet, 2021-03-30:
Thak you. Problem is solved. Nice work.

Closed 2021-03-30.

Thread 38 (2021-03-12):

Custom Buttons Not Reloading After Reconnection to WiFi

IIAIronWolf, 2021-03-12:
I have an issue with my ISP currently that causes my WiFi to go out every now and then. To fix the issue, I have to restart my modem and router.
I noticed that while the router was restarting, the HASP went back to AP mode, showing the QR code. When the WiFi reconnected, the custom buttons I had made for b(4) and b(6) of the alarm page had gone back to the Core Functionality defaults.
I had to manually run the automations to reset the buttons; however, I also noticed later that day that the buttons had yet again gone back to the core functionality defaults.

aderusha, 2021-03-15:
Can you explain a little bit about what you mean by custom buttons for b[4] and b[6]?  The core automation should only be touching buttons 1-3 on each page.  Do you have the alarm blueprint deployed?

IIAIronWolf, 2021-03-28:
I have deployed the alarm blueprint, but I don't like the new, non-colorized button for b(4) and b(6) that used to be in the old HASP demo. So I created my own custom buttons that change colors based on alarm state, like your old demo used to. However, when the HASP reconnects to wifi, those customization are lost.

aderusha, 2021-03-29:
Can you post the code you are using?  It sounds like you've deployed the Alarm blueprint, then also deployed some additional automations that interact with the same buttons.  You need to be pretty careful about that process for it to work, as you'll have two different sets of automations fighting for control over the same objects.  As a general rule, the last automation to fire "wins".

IIAIronWolf, 2021-04-13:
That being the case, it would seem the only way to get around this is to change the automation that your blueprint creates since there is currently no way to colorize the buttons?

aderusha, 2021-04-14:
Editing the blueprint locally is probably the best approach here.  It's why you don't see a lot of "all in one" blueprints published by me.  While several users have asked for this, I find having 12 buttons all defined in a single blueprint is bound to lead to issues like you've described.  You either take the blueprint as-is, or you're stuck changing the whole thing because you want to make a couple small changes.

It's the tradeoff that comes with a solution like this.

Closed 2021-04-14.

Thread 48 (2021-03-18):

Struggling to convert to NX4832T035_011R

OliPassey, 2021-03-18:
Hey,
I have two NX4832T035_011R, and one 2.4" all were running on the older version of HASP.
I've moved and got a new HA install on the go - tried to convert the vanilla nextion file into one that'll work with my NX4832T035_011R - but i get an error on model match.
I can't seem to select the NX4832T035_011R in nextion editor, only NX4832T035_011 shows up.

Do you know how i can amend this before compiling?

Looking forward to trying out the new version!

aderusha, 2021-03-29:
Hey sorry for the delayed response - did you ever find a resolution to this issue?

OliPassey, 2021-03-29:
No worries - no, sadly not yet.
A bit stumped on selecting the correct hardware - didn't have this issue last time round - wondering how i managed to flash them the first time round if the model numbers don't line up.

aderusha, 2021-03-29:
Yeah that has me a little stumped.  One suggestion I'll throw out - maybe try the [Unofficial Nextion Forums](https://unofficialnextion.com/).  We have a pretty diverse crowd there who might have a bit more experience with the specific model you're working with.

The "official" support forums are a little... difficult to deal with, so I created this site for Nextion users to work together without needing to deal with the Nextion organization themselves.  If you've ever had the misfortune of doing so, you'll understand why this was (sadly) necessary :|

OliPassey, 2021-03-29:
Thanks, appreciate the steer.
I'll take another look at this asap and let you know how i get on.

fvanroie, 2021-04-18:
>  I can't seem to select the NX4832T035_011R in nextion editor, only NX4832T035_011 shows up.

The R is the product code shouldn't make any difference, did you try to compile and upload from the `NX4832T035_011` instead?

OliPassey, 2021-04-20:
Managed to get things working on what i suspect is the original tft file i created for the previous iteration of HASP.

I have 2x 3.5's & 1x 2.4 - all are now working, but i messed up the font values on my file when i first created (kind of how i know the screens are still on the old firmware) i'm going to dig out the original HMI file, fix the font issues and re-compile.

Once i've finished i'll post the file here in case it's useful for anyone else.

@fvanroie - yes, thats what i compiled, and when uploading the screen showed a mismatch on just the _11R - i'll take screenshots if i can recreate it.

Either way, i have touchscreen controls back in my life - thanks for an awesome new version, loving the blueprint import function!

OliPassey, 2021-04-20:
Not sure if this was my mistake or the software being odd.
I've re-selected the device, recompiled and this time it's accepted the file.

I can't work out what was wrong as selected device didn't change anywhere visibly in the GUI.

Anyway, files for anyone who may want it / find it useful.
It's not perfect but it'll save someone the time of resizing everything.
You'll also want to amend the message on p0 :)

Closed 2021-04-22.

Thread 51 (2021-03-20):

Multi Gang Installation

omayhemo, 2021-03-20:
Unfortunately the included custom printed enclosure doesn't allow for mounting with-in a 2 or more gang.  The instructions also lack any detail about wiring.  Is there no ground, just neutral and line?

aderusha, 2021-03-20:
There are [several multi-gang models available](https://github.com/HASwitchPlate/HASPone/tree/main/3D_Printable_Models), and if you don’t find a variation that fits your needs, let me know and I can probably whip something up.

You are correct on the lack of ground, there are no exposed conductive surfaces so a separate ground is not needed.

omayhemo, 2021-03-20:
Thanks Allen,

I don't have a 3d printer.  Do you sell a 3 gang plate, with two paddles on one side, your HASPone on the other?

aderusha, 2021-03-21:
I do! For $15 I will print and ship a custom 3 gang plate to your specification.  Send $15 to paypal@svideo.org along with the specific layout you are looking for.  If you want HASP on the left, with a Decora ("paddle") in the middle and also on the right, send me something like "HASP | Decora | Decora" so I know exactly what you're after.

omayhemo, 2021-03-21:
Thanks Allen, Sent with note, but just in case
HASP | Decora | Decora

Closed 2021-03-21.

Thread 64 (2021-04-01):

landscape layout for Nextion Display 7-10 inch and more the same page in HASP

bluetech1-api, 2021-04-01:
I have a Nextion 7 inch and it look so not really well with portrait layout, so can I have fix some code to make it work as a landscape layout? I intend to buy a bigger one for nextion 10 inch, but if it can not work with landscape layout so it look so good. BTW, what should I do if I want more pages in HASP Page, example, I want 03 page 9 and 03 page 7 for all my suitable devices, is it possible?
Thanks for your help.

aderusha, 2021-04-01:
Both of the above are possible, but you're going to need to do a bit of work in the Nextion editor.  Also, the 10 inch model pulls more current than the power supply on the PCB can handle, so you'll either need external power or you'll need to develop your own PCB with footprint for a much larger display.

So, possible on both accounts, but not straightforward.  You'll have some work in front of you to make it happen.

bluetech1-api, 2021-04-02:
thanks aderusha, beside the power supply and a bit of work in the Nextion editor to resize the layout, so how about esp sketch and Home_Assistant/blueprints? where is I can begin exactly?

aderusha, 2021-04-02:
The ESP side should work fine, and the blueprints should work with the exception of the 4 "with icon" blueprints, which would need to be modified to place the overlay icon in the right spot.  That's mostly a cosmetic issue, and others have done similar work with other sizes of Nextion device.

Closed 2021-04-01.

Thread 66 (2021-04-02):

Wifi Connected! screen keeps showing intermittently

omayhemo, 2021-04-02:
I've installed and configured the device.  Loaded the core blueprint and automation as well as configured a couple button automations.

Frequently the WiFi Connected! screen flashes up shows the SSID, IP Address and MQTT Connection IP, then within a second returns to the button screen.  Despite this, it worked fine for a while, except for the screen intermittently changing as mentioned.

aderusha, 2021-04-02:
What version of HASPone are you running?  If 1.00, can you try upgrading to 1.01 and see if the issue persists?

omayhemo, 2021-04-02:
1.01 resolved the periodic display of that WiFi view, however I can no longer connect to it via browser and IP.

omayhemo, 2021-04-02:
Spoke too soon, it's doing it again.  I'm guessing it's loosing wifi periodically and this screen displays when it connects?

aderusha, 2021-04-02:
That's correct, for some reason you're dropping off of WiFi.  Getting a debug log remotely via telnet can be tricky in these situations for obvious reasons. Somewhere near the bottom of the admin web page you should see a value for Signal Strength.  What is that reading right now?

Also, what kind of wifi APs are you running?  Are they able to tell you anything interesting about the event?

omayhemo, 2021-04-02:
Not great. -81db
I know this room has weak wifi. So this much be the problem.

Closed 2021-04-02.

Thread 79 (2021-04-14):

Plate Stuck on Setup Screen

npeskoe, 2021-04-14:
I have successfully paired my plate with HA and have downloaded the blue prints. I have tried to run automations to get the device fully set up and functioning, but it is stuck on the Wifi Connected/MQTT Connected Screen. I have tried rebooting the device and updating the firmware, but am not having any luck. Can someone please assist?

Thanks

damanti-me, 2021-04-15:
is there a mqtt error code on the display?
what does your broker shows in the log?

npeskoe, 2021-04-15:
No error on the display. It says wifi and mqtt are both connected.

This is the log when I reboot the device:

[08:32:53] WARNING: [WARN] Not found homeassistant on local database
1618489973: Socket error on client <unknown>, disconnecting.
1618490256: New connection from 172.30.32.1 on port 1883.
1618490256: Socket error on client <unknown>, disconnecting.
1618490258: New connection from 172.30.32.1 on port 1883.
1618490258: Socket error on client <unknown>, disconnecting.
1618490260: New connection from 172.30.32.1 on port 1883.
1618490260: Socket error on client <unknown>, disconnecting.
1618490264: New connection from 172.30.32.1 on port 1883.
1618490264: Socket error on client <unknown>, disconnecting.
1618490272: New connection from 172.30.32.1 on port 1883.
1618490272: Socket error on client <unknown>, disconnecting.
1618490288: New connection from 172.30.32.1 on port 1883.
[08:38:09] WARNING: [WARN] Not found homeassistant on local database
1618490289: Socket error on client <unknown>, disconnecting.
1618490321: New connection from 172.30.32.1 on port 1883.
1618490321: Socket error on client <unknown>, disconnecting.
1618490385: New connection from 172.30.32.1 on port 1883.
1618490385: Socket error on client <unknown>, disconnecting.
1618490496: Client peskoeplate-e8db84c5e5db disconnected.
1618490498: New connection from 192.168.1.233 on port 1883.
[08:41:39] INFO: [INFO] found npeskoe on Home Assistant
1618490499: New client connected from 192.168.1.233 as peskoeplate-e8db84c5e5db (p2, c1, k30, u'npeskoe').
1618490505: New connection from 172.30.32.1 on port 1883.
1618490505: Socket error on client <unknown>, disconnecting.
1618490625: New connection from 172.30.32.1 on port 1883.
[08:43:46] WARNING: [WARN] Not found homeassistant on local database
1618490626: Socket error on client <unknown>, disconnecting.
1618490746: New connection from 172.30.32.1 on port 1883.
1618490746: Socket error on client <unknown>, disconnecting.
1618490866: New connection from 172.30.32.1 on port 1883.
1618490866: Socket error on client <unknown>, disconnecting.

damanti-me, 2021-04-15:
Try this link@https://community.home-assistant.io/t/there-is-no-homeassistant-local-user-in-the-database/204207

npeskoe, 2021-04-15:
Thank you very much. @damanti-me That fixed it.

Closed 2021-05-16.

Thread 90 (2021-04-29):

Errors produced during setup. Non functioning panel.

Is0mniac, 2021-04-29:
Hello, I bought a new Haspone from you, and I am having multiple errors during setup. It connects to my mqtt server (run on external rasp pi, home assistant is running as the virtual env package for synology), and connects to my wifi. Deploying the core integration, however gives me nothing, the device doesn't reboot, stays on WiFi connected, and Mqtt Connected screen. It doesn't reboot as stated in the instructions. If I touch the panel it does take me to an updated version of the page views, and I am able to see the page buttons below, but nothing for buttons 4-7 on any of the pages. Deploying a blueprint for anything fails to run. I am getting multiple errors in my logs. The buttons all remain blank except the bottom navigation labels.

homeassistant.components.automation.new_automation
Source: components/automation/__init__.py:452
Integration: Automation (documentation, issues)
First occurred: 5:35:07 AM (86 occurrences)
Last logged: 5:51:07 AM

Error rendering variables: UndefinedError: None has no element 0

homeassistant.components.automation.hasp_core_functionality_3
Source: helpers/script.py:1324
Integration: Automation (documentation, issues)
First occurred: 5:37:31 AM (2 occurrences)
Last logged: 5:37:31 AM

HASP Core functionality: Choose at step 1: choice 1: Error executing script. Error for call_service at pos 10: Error rendering data template: UndefinedError: None has no element 0
HASP Core functionality: Error executing script. Error for choose at pos 1: Error rendering data template: UndefinedError: None has no element 0

homeassistant.components.automation.hasp_core_functionality_3
Source: components/automation/__init__.py:504
Integration: Automation (documentation, issues)
First occurred: 5:37:31 AM (1 occurrences)
Last logged: 5:37:31 AM

Error while executing automation automation.hasp_core_functionality_3: Error rendering data template: UndefinedError: None has no element 0

I am not sure if this is related to home assistant updates or some other issue. Can you please guide me on how to fix this?

Thank you so much!

raa1n, 2021-04-29:
I have the exact issue except that I built the HASP myself instead of buying one directly. I can see that it is connected to my wifi and MQTT connection is established.

When I run the core functionality blueprint, I get the same error logged above and the HASP display doesn't change either

Thanks in advance for the solution (hopefully..!!!)

aderusha, 2021-05-03:
@Is0mniac and @raa1n -[ check out this post](https://github.com/HASwitchPlate/HASPone/discussions/93#discussioncomment-686020) for what I think should be a solid solution.  If you update, let me know how it goes and if everything looks good I'll push this release to the main branch.

Is0mniac, 2021-05-03:
It works!! Thank you much.

aderusha, 2021-05-16:
@raa1n how are things looking for you buddy?  The test version I posted above is now release v1.02.  Is everything working on the new codebase?

aderusha, 2021-06-18:
Closing as OP has been resolved.

Closed 2021-06-18.

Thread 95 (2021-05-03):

Blueprint "HASP p[x].b[y] displays the current temperature with icon and colors" fails with temperature sensor

rebel7580, 2021-05-03:
When creating an automation from this blueprint and selecting a temperature sensor instead of a weather provider, the automation fails. When saved, no "Run" is shown, and the automation does not show in the Automation list. The automations do show up in automations.yaml.

The homeassitant log shows the following ERRORs (tried twice with two different temperature sensors):

2021-05-03 16:19:26 ERROR (MainThread) [homeassistant.components.automation] Blueprint HASP p[x].b[y] displays the current temperature with icon and colors generated invalid automation with inputs OrderedDict([('haspdevice', 'cfc57889d19f2ce169bf924e4d916c67'), ('hasppage', 2), ('haspbutton', 5), ('temperature_sensor', 'sensor.outside_temp'), ('colortemp', True)]): Entity IDs can not be None for dictionary value @ data['entity_id']. Got None

2021-05-03 16:19:27 ERROR (MainThread) [homeassistant.components.automation] Blueprint HASP p[x].b[y] displays the current temperature with icon and colors generated invalid automation with inputs OrderedDict([('haspdevice', 'cfc57889d19f2ce169bf924e4d916c67'), ('hasppage', 2), ('haspbutton', 4), ('temperature_sensor', 'sensor.hotwater_am2301_temperature'), ('colortemp', True)]): Entity IDs can not be None for dictionary value @ data['entity_id']. Got None

When choosing a weather provider instead, the automation is successful and is shown inthe Automation list.

I know almost zero about blueprint/automation coding, but these lines in hasp_Display_Temperature_with_Icon_and_Colors.yaml look suspicious to me:

```
381: trigger:
382: - platform: state
383:   entity_id: !input 'weather_provider'
```

rebel7580, 2021-05-06:
I'm definately a noobie when it comes to HA and yaml, so take this FWIW:

There seems to be two issues here:
1) the trigger for weather_provider will fail if no weather provider is defined,
2) there is no trigger for the temperature sensor, if defined.

I tried this
```
trigger_variables:
   ...
  weather_provider: !input 'weather_provider'
  temperature_sensor: !input 'temperature_sensor'
  entityid: '{%- if temperature_sensor|lower == "none" -%}  {{- weather_provider -}} {%- else -%}  {{- temperature_sensor -}} {% endif %}'
trigger:
- platform: state
  entity_id: '{{ entityid }}'
```
but this causes an error also, probably based on mal-formed yaml on my part. The idea was to set 'entity_id' to either the weather entity or the temperature entity.

Of course, I may completely misunderstand this code!

rebel7580, 2021-05-19:
Since those new trigger variables didn't work, I reverted back and then as an experiment, simply changed the trigger entity like this:
```
381: trigger:
382: - platform: state
383:   entity_id: !input 'temperature_sensor'
```
This allowed temperature sensor entities to work assuming one was entered in the blueprint, but of course weather ones now don't.

aderusha, 2021-07-08:
I've done some digging into this and based on conversations with some of the Nabu Casa folks.. what I'm trying to do there cannot be done.  Triggering on entity state change with a blueprint must be in the format of `entity: !input <some_input_entity>`.  That means you can't make decisions before the trigger condition as to which entity should be used, and you can't trigger on both unless you force the user to assign both.

I'm not quite sure how to proceed on this one.  One solution might be to revert this blueprint back to a weather-only solution, then to create a second blueprint which allows a sensor instead of a weather entity.  And if I do that... maybe it could be more general, such that one can define 5 different icons and ranges which default to the temperature icons (but allow the user to substitute in any other icons).  That way, one could use it with any sensor to display the current value and have colors+icons along for the ride.

rebel7580, 2021-07-09:
> I've done some digging into this and based on conversations with some of the Nabu Casa folks.. what I'm trying to do there cannot be done. Triggering on entity state change with a blueprint must be in the format of `entity: !input <some_input_entity>`. That means you can't make decisions before the trigger condition as to which entity should be used, and you can't trigger on both unless you force the user to assign both.

Well, at least I don't feel too dumb not being able to figure out how to do it! :)

> I'm not quite sure how to proceed on this one. One solution might be to revert this blueprint back to a weather-only solution, then to create a second blueprint which allows a sensor instead of a weather entity. And if I do that... maybe it could be more general, such that one can define 5 different icons and ranges which default to the temperature icons (but allow the user to substitute in any other icons). That way, one could use it with any sensor to display the current value and have colors+icons along for the ride.

That's s good idea, one for weather, and one similar for general sensor.

In my case, since I use HA only as an "add-on" to do a few things that are hard for my own home automation system to do, I've dropped using the Hasp blueprints and implemented similar functionallity in my system (and modeled some of the logic from the blueprints). That way, I have fewer points of possible failure for critical things.

I have several inside and outside temp/hum sensors that display and look a lot like yours. For the outside ones, I've also include a "feels like" temp display based on temp and humidity and wind speed. I also color that one with a range of blue-green-yellow-orange-red depending on value.  It's been mostly red these last few days! I plan to add the 5-range temp icons soon (right now it's just showing the max temp icon).

Thanks for this great project!

rebel7580, 2021-09-07:
Should this be closed via commit: https://github.com/HASwitchPlate/HASPone/commit/8194fc273bfdf46425f21e6e48fc103503140e9c
which removed temp sensor from selection? Or are you waiting until/if you do a temp sensor version before closing this one?

aderusha, 2021-09-08:
> are you waiting until/if you do a temp sensor version before closing this one?

Yup, just need to get off my duff and finish up the temp sensor version, and I'm leaving this open to annoy me until I do that :D

aderusha, 2021-11-18:
OK I think I have this sorted: https://github.com/HASwitchPlate/HASPone/discussions/152

Closed 2021-11-18.

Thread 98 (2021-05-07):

Arduino Sketch Build Issues

blaxer, 2021-05-07:
I am struggling to get the Arduino sketch to build properly, the link to the documentation for the ardunio sketch on this page:

https://github.com/HASwitchPlate/HASPone/tree/main/Arduino_Sketch

is broken and the documentation here:

https://github.com/aderusha/HASwitchPlate/blob/master/Documentation/01_Arduino_Sketch.md

appears to be out of date.

I suspect that ESP8266 version 2.5.0 may no longer be the correct board version? In addition, ESP8266Ping does not appear to be avilable in the library manager but this might be the library?

https://github.com/dancol90/ESP8266Ping

Any information around how to succesfully build the sketch would be very much appreciated! TIA!

aderusha, 2021-05-15:
If you use platformio, here's what I have in my platformio.ini:

```ini
[env:d1_mini]
platform = espressif8266
board = d1_mini
framework = arduino
board_build.f_cpu = 160000000L
board_build.ldscript = eagle.flash.4m1m.ld
build_flags =
  -D PIO_FRAMEWORK_ARDUINO_ESPRESSIF_SDK22x_191122
  -D PIO_FRAMEWORK_ARDUINO_LWIP2_HIGHER_BANDWIDTH
monitor_filters = esp8266_exception_decoder
lib_deps =
  ArduinoJson
  MQTT
  dancol90/ESP8266Ping@^1.0
  krzychb/EspSaveCrash@^1.2.0
```

aderusha, 2021-06-18:
@blaxer are you all set?

shafr, 2021-06-23:
Also libs I used was:
```
lib_deps =
      krzychb/EspSaveCrash @ ^1.2.0
      tzapu/WiFiManager @ ^0.16.0
      bblanchon/ArduinoJson         @ ^6.18.0
      256dpi/MQTT @ ^2.5.0
      dancol90/ESP8266Ping @ ^1.0
```

saikek, 2021-07-01:
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

aderusha, 2021-07-06:
I'm now going to start including a working `platformio.ini` in future firmware build updates to allow folks to pull the correct versions of any included libraries to make building the project a bit easier.  Currently, that file looks like this on the 1.03 dev branch:

```ini
[env:d1_mini]
platform = espressif8266
board = d1_mini
framework = arduino
board_build.f_cpu = 160000000L
board_build.ldscript = eagle.flash.4m1m.ld
build_flags =
    -D PIO_FRAMEWORK_ARDUINO_ESPRESSIF_SDK22x_191122
    -D PIO_FRAMEWORK_ARDUINO_LWIP2_HIGHER_BANDWIDTH
lib_deps =
    bblanchon/ArduinoJson @ ^6.18.1
    256dpi/MQTT @ ^2.5.0
    dancol90/ESP8266Ping @ ^1.0
    krzychb/EspSaveCrash @ ^1.2.0
    https://github.com/tzapu/WiFiManager.git#8984863fe6a8106bf0ead7e6ac013c745a4d1f93
```

fvanroie, 2021-07-06:
It also allows you to set up a CI/CD pipeline where Github Actions will automatically build the firmware from source on every commit, etc...

Closed 2021-07-06.

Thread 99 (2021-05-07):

Dropped config on restart

OliPassey, 2021-05-07:
I've got a few HASPone units going, but they seem to drop their config on a reboot of HA or the device itself.
I have to re-run automations to get things looking right again, this used to be automatic - have i missed a step?

Any advice you can offer would be greatly appreciated.

aderusha, 2021-05-15:
What configuration is being dropped?  The configuration of the device itself (the items seen on the web admin page), or blueprint config?  Something else?

OliPassey, 2021-05-15:
Sorry, should have been more clear.
All the text labels and button presses I've added are not sent to the device and I have to manually rerun my automation to populate the device again. Otherwise it connects and just has blank buttons on all pages.

Get Outlook for Android<https://aka.ms/AAb9ysg>

________________________________
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

aderusha, 2021-05-15:
Can you take a look at [this procedure](https://github.com/HASwitchPlate/HASPone/discussions/102#discussioncomment-741804) and see if that resolves anything?

OliPassey, 2021-05-16:
No duplicate devices have been created, but in troubleshooting today i saw v1.0.2 was available.
Upgrading has seemed to solve it, i can now reboot the device and they'll automatically populate as before.

Not sure what the exact problem ended up being - but hey - working now.

Thanks for the advice 👍

Closed 2021-05-16.

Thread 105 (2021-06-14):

Odd json state return when querying text attribute

rebel7580, 2021-06-14:
I'm using the hasp with my own MQTT based home automation system.  I do use the default display sw.
HASP Version: 1.02
LCD Version: 3

Right now, I just have page 1 defined with actual button values. If I query the txt attribute, I not only get a state button response with the correct text, but also get a state json response from p[7].b[15] with the same text. This is the log from my system:
```
12:06:35.991 mqttx: Published hasp/hasp01/command/p[1].b[7].txt, !
12:06:36.001 mqttx: Received PUBLISH (d0, q0, r0, 'hasp/hasp01/state/p[1].b[7].txt', ... (9 bytes))
12:06:36.002 hasp: hasp: topic:hasp/hasp01/state/p[1].b[7].txt,msg:Overcast ;
12:06:36.008 mqttx: Received PUBLISH (d0, q0, r0, 'hasp/hasp01/state/json', ... (46 bytes))
12:06:36.009 hasp: hasp: topic:hasp/hasp01/state/json,msg:{"event":"p[7].b[15].val","value":"Overcast "};
```
You can see the correct "Overcast " response for p[1].b[7], but the json is reported mistakenly from p[7].b[15]!

Here is the response if I query p[7].b[15] directly:

```
12:06:42.265 mqttx: Published hasp/hasp01/command/p[7].b[15].txt, !
12:06:42.273 mqttx: Received PUBLISH (d0, q0, r0, 'hasp/hasp01/state/p[7].b[15].txt', ... (0 bytes))
12:06:42.274 hasp: hasp: topic:hasp/hasp01/state/p[7].b[15].txt,msg:;
12:06:42.278 mqttx: Received PUBLISH (d0, q0, r0, 'hasp/hasp01/state/json', ... (37 bytes))
12:06:42.280 hasp: hasp: topic:hasp/hasp01/state/json,msg:{"event":"p[7].b[15].val","value":""};
```
You can see that both the state button and state json responses are the correct empty value.

Sending queries to page 1 buttons 4-7 yield the same response from page 7 button 15.

But, further testing shows that querying button 4 on any page (or any other valid button for that page)  returns the incorrect page/button for the json return (but the correct attribute value).  So while the second log above seems to show a correct json response for page 7 button 15, that's just a coincidence since queries to ALL page have in the response page 7 button 15 as the button address.  And it doen't always return p[7].b[15] in the json. the actual page/button seems to change based on query history and page selections. At one point during my testing of this issue, the json return changed to p[11].b[5].

Possibly, there is some incorrect "memory" somewhere that is being used as the json page/button value in the return (although the actual text attribute value is returned properly).

New info:  The page/button returned in the json appears to be that of the last button pressed. So this is where the bad page/button number is coming from.

Steps to reproduce:
- Go to any page.
- press a button
- via MQTT, query another page/button text value.
- See that the "event" page/button shown in the json return is the button pressed in step 2, not the page/button of the query. Note that the "value" in the response is correct for the query page/button.

aderusha, 2021-07-06:
Finally getting around to digging into this and I am unable to reproduce this behavior using the steps provided and I'm hoping you can help me out.

## MQTT log

```
1. hasp/plate01/command/page       8
2. hasp/plate01/state/json {"event":"page","value":8}
3. hasp/plate01/state/page 8
4. hasp/plate01/state/p[8].b[4]    ON
5. hasp/plate01/state/json {"event_type":"button_short_press","event":"p[8].b[4]","value":"ON"}
6. hasp/plate01/state/p[8].b[4]    OFF
7. hasp/plate01/state/json {"event_type":"button_short_release","event":"p[8].b[4]","value":"OFF"}
8. hasp/plate01/state/p[8].b[4].val        0
9. hasp/plate01/state/json {"event":"p[8].b[4].val","value":0}
10. hasp/plate01/command/p[1].b[4].txt
11. hasp/plate01/state/p[1].b[4].txt        Text to display test 1 2 3
12. hasp/plate01/state/json {"event":"p[8].b[4].val","value":"Text to display test 1 2 3"}
```

## Explanation:

**1:** I send MQTT command to switch to page 8
**2-3:** HASPone replies with current page on JSON and state topics
**4-7:** At the device I press and then release `p[8].b[4]` and the HASPone send the `ON` and `OFF` messages on JSON and state topics
**8-9:** HASPone sends current value of `p[8].b[4]`
**10:** I send MQTT message querying the value of `p[1].b[4].txt`
**11-12:** HASPone replies with current value of `p[1].b[4].txt` on JSON and state topics

rebel7580, 2021-07-06:
Actually, your test shows the problem!  Note step 12 json event reports using p[8].b[4].val, not p[1].b[4].val like step 11, although the actual value IS correct for p[1].b[4].

Tried this again with same results as before.
Note:  "mqttx" is my mqtt client log, "hasp" is my hasp app log.
```
SEND PAGE 3 COMMAND:
06/11:24:06.866 mqttx: Published hasp/hasp01/command/page, 3!

RECEIVE RESPONSE:
06/11:24:06.920 mqttx: Received PUBLISH (d0, q0, r0, 'hasp/hasp01/state/json', ... (26 bytes))
06/11:24:06.921 hasp: hasp: topic:hasp/hasp01/state/json,msg:{"event":"page","value":3};
06/11:24:06.922 mqttx: Received PUBLISH (d0, q0, r0, 'hasp/hasp01/state/page', ... (1 bytes))
06/11:24:06.923 hasp: hasp: topic:hasp/hasp01/state/page,msg:3;

PRESS BUTTON 3,4 (no content! i.e., not programmed with a text value.)
06/11:24:13.679 mqttx: Received PUBLISH (d0, q0, r0, 'hasp/hasp01/state/p[3].b[4]', ... (2 bytes))
06/11:24:13.680 hasp: hasp: topic:hasp/hasp01/state/p[3].b[4],msg:ON;
06/11:24:13.686 mqttx: Received PUBLISH (d0, q0, r0, 'hasp/hasp01/state/json', ... (68 bytes))
06/11:24:13.687 hasp: hasp: topic:hasp/hasp01/state/json,msg:{"event_type":"button_short_press","event":"p[3].b[4]","value":"ON"};

MY APP RESPONDS BY LIGHTING THE DISPLAY:
06/11:24:13.689 mqttx: Published hasp/hasp01/brightness/set, 100!
06/11:24:13.690 mqttx: Published hasp/hasp01/light/switch, ON!

HERE'S THE OFF RESPONSE:
06/11:24:13.995 mqttx: Received PUBLISH (d0, q0, r0, 'hasp/hasp01/state/p[3].b[4]', ... (3 bytes))
06/11:24:13.996 hasp: hasp: topic:hasp/hasp01/state/p[3].b[4],msg:OFF;
06/11:24:14.000 mqttx: Received PUBLISH (d0, q0, r0, 'hasp/hasp01/state/json', ... (71 bytes))
06/11:24:14.001 hasp: hasp: topic:hasp/hasp01/state/json,msg:{"event_type":"button_short_release","event":"p[3].b[4]","value":"OFF"};

06/11:24:14.003 mqttx: Received PUBLISH (d0, q0, r0, 'hasp/hasp01/state/p[3].b[4].val', ... (1 bytes))
06/11:24:14.004 hasp: hasp: topic:hasp/hasp01/state/p[3].b[4].val,msg:0;
06/11:24:14.007 mqttx: Received PUBLISH (d0, q0, r0, 'hasp/hasp01/state/json', ... (35 bytes))
06/11:24:14.008 hasp: hasp: topic:hasp/hasp01/state/json,msg:{"event":"p[3].b[4].val","value":0};

REQUEST TXT VALUE FOR 1,7 ("Clear"):
06/11:24:21.063 mqttx: Published hasp/hasp01/command/p[1].b[7].txt, !
06/11:24:21.074 mqttx: Received PUBLISH (d0, q0, r0, 'hasp/hasp01/state/p[1].b[7].txt', ... (6 bytes))
06/11:24:21.075 hasp: hasp: topic:hasp/hasp01/state/p[1].b[7].txt,msg:Clear ;
06/11:24:21.076 mqttx: Received PUBLISH (d0, q0, r0, 'hasp/hasp01/state/json', ... (42 bytes))
06/11:24:21.077 hasp: hasp: topic:hasp/hasp01/state/json,msg:{"event":"p[3].b[4].val","value":"Clear "};
```
Note Event report has wrong button designation - 3,4 instead of 1,7 - but reports 1,7 value correctly.

Tried with a button that had been previously set to a txt value, and same thing happens.
The event report always uses the button address of the last button pressed, not the one aksed for.

aderusha, 2021-07-06:
Oh man I can't believe I missed that, thanks for the catch!  Got it, now I have the test case so I suspect I need to fix it :D

Thanks @rebel7580 , ball is squarely in my court.

aderusha, 2021-07-06:
Now that I know what the heck I'm looking at (thanks to the gentle guidance from @rebel7580) I think I've resolved the issue.  Dumb error in the firmware, and I believe I've identified and fixed the issue in the [1.03 branch](https://github.com/HASwitchPlate/HASPone/tree/1.03-HASPone-firmware).  Testing now returns the correct object ID both in the standard namespace and in the JSON object returned.

If you want to test with the current dev release, run the web admin firmware update and paste in the following URL: `https://raw.githubusercontent.com/HASwitchPlate/HASPone/1.03-HASPone-firmware/Arduino_Sketch/HASwitchPlate.ino.d1_mini.bin`

rebel7580, 2021-07-06:
Tested your dev build. Looks fixed! Thanks!

aderusha, 2021-11-10:
[Fix released in HASPone v1.03](https://github.com/HASwitchPlate/HASPone/discussions/146)

rebel7580, 2021-11-10:
Hi Allen -
Is the official 1.03 the same as the 1.03 branch mentioned on the 6 Jul post? Wondering if I need to upgrade if I already have the Jul branch version.

aderusha, 2021-11-10:
It has been updated since then, so you'll want to apply the release version.  If you go to the firmware update page and just let it use the default URL, you'll be applying the 1.03 release version.

rebel7580, 2021-11-10:
Updated my two hasps. Thanks!

aderusha, 2021-11-10:
Thank you for all the helpful feedback and bug hunting!

Closed 2021-11-10.

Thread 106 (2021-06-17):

Very concerned about the many warninings in log wile useing Heatpump blueprints.

ssirkakriss, 2021-06-17:
I've been using HASwitchPlate/HASPone  for a bout 2 months. It works great for me, except for one blueprint. The heatpump blueprints. The blueprint seems to work fine, except it produces a lot of warnings in the log. I'm concerned after an upcoming update to HA in Oct. well turn the warnings in to errors. Link to update info: https://www.home-assistant.io/blog/2021/04/07/release-20214/#warnings-for-undefined-variables-in-templates.

The warnings I see in HA log.:
~~~
Logger: homeassistant.helpers.template
Source: helpers/template.py:1366
First occurred: June 13, 2021, 8:53:05 AM (2190 occurrences)
Last logged: 7:34:33 AM

Template variable warning: 'hp_is_off' is undefined when rendering '{%- if hp_is_off -%}heat_cool{%- else -%}off{%- endif -%}'
~~~

Is this something to worry about?
Can the warnings be remedied?
I not a good coder but I get the gist of what the blog post is telling me. Sort of.

aderusha, 2021-06-22:
You are spot-on with your assessment of the situation.  This is OK for now, but won't be in October.  I don't have a heat pump here to test on, but am reaching out to the original developer of this blueprint for assistance in addressing the undeclared variable issues.

If anyone else has a heatpump setup, feel free to jump in here :D

aderusha, 2021-06-23:
@ssirkakriss - @SittingDuc has issued a PR for the page 6 heatpump blueprint.  Are you using page 6 or page 9?  If page 6, can you test to see if this resolves the issue?

SittingDuc, 2021-06-23:
Hello, my pr actually touched both page6 and page9, so either and both
should be happier/warning-free now. Would love to hear if it fixes the
issue for you

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

ssirkakriss, 2021-06-23:
I've removed the old blueprint and associated automation from my setup(s) and applied SittingDuc's PR (/SittingDuc/HASPone/blob/f092966202d452dcd508a5390fb3126b9c6f3c71/Home_Assistant/blueprints/hasp_Display_Heatpump_Control_page6.yaml. )
Note: Ive not tried Page 9 BP. As My setup(s) use page 6 BP.

I'm happy to report issue appears resolved.
Many Thanks to all.

Closed 2021-06-23.

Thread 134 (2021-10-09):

Error: Template warning: 'round'

xHirscHx, 2021-10-09:
Im getting this.

Logger: homeassistant.helpers.template
Source: helpers/template.py:1210
First occurred: 5:14:30 PM (3 occurrences)
Last logged: 5:14:30 PM

Template warning: 'round' got invalid input 'None' when rendering template '{%- if roundtemp == true -%} {{- state_attr(weather_provider, "temperature") | round -}} {%- else -%} {{- state_attr(weather_provider, "temperature") -}} {%- endif -%}' but no default was specified. Currently 'round' will return 'None', however this template will fail to render in Home Assistant core 2021.12

aderusha, 2021-11-10:
Thanks for the head's up @xHirscHx !  I've pushed updates to all blueprints which should address this warning in the log.  [Here's some info on that](https://github.com/HASwitchPlate/HASPone/discussions/143).

If you don't update, the device should still function but will continue to log errors.  The updated blueprints should avoid those log messages.

aderusha, 2021-11-18:
Closing issue after releasing fixes to impacted blueprints

Closed 2021-11-18.

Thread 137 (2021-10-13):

Crash on Wifi Connect

0xJoeMartin, 2021-10-13:
I have built a HASP and uploaded the Arduino sketch.  I am getting the HASP Wifi Setup screen on the Nextion but when I connect to the "HASwitchPlate" SSID, the ESP crashes and restarts.  Serial Monitor output:

================================================================================
[+0.071s] SYSTEM: Starting HASwitchPlate v1.02
[+0.076s] SYSTEM: Last reset reason: Fatal exception:3 flag:2 (Exception) epc1:0x4000bf64 epc2:0x00000000 epc3:0x00000000 excvaddr:0x40285469 depc:0x00000000
[+0.090s] SYSTEM: heapFree: 30992 heapMaxFreeBlockSize: 30896
Crash information recovered from EEPROM
Crash # 1 at 4660 ms
Restart reason: 2
Exception cause: 3
epc1=0x4000bf64 epc2=0x00000000 epc3=0x00000000 excvaddr=0x40285469 depc=0x00000000
>>>stack>>>
3ffff900: 3fff7014 00000ca0 00000000 00000000
3ffff910: 40285469 0000000b 3ffff960 00000000
3ffff920: 00000000 3ffffb60 3ffff99c 402221ab
3ffff930: 00000000 3fff535c 3ffff960 4022c140
3ffff940: 3ffff960 3ffffc98 3ffffb60 4022c169
3ffff950: 3ffffc60 3ffffc98 3ffffb60 402270ee
3ffff960: 3fff6854 000b000f 80000000 00000030
3ffff970: 00004bc6 00000000 00000000 00000000
3ffff980: 0024002f 00000000 00000000 6567412d
3ffff990: 3fff5944 3fff5a08 00000000 3fff7014
3ffff9a0: 0ca00caf 80000000 00000000 00000000
3ffff9b0: 3ffffc60 00000001 3fff192c 40239080
3ffff9c0: 00000000 00000000 00000000 401000e9
3ffff9d0: 00000000 4bc6a7f0 00000000 40203271
3ffff9e0: 00000000 3fff5944 3fff58fc 40205e8e
3ffff9f0: 00000000 3ffffc60 40100989 00000000
3ffffa00: 0000103f 00000000 00000000 00000001
3ffffa10: 00000000 00000000 3fff58fc 00000000
3ffffa20: 3ffffc60 3fff5920 3fff58fc 40207d7e
3ffffa30: 40239eb4 00000000 00001388 40237447
3ffffa40: 00000000 00000000 3fff6df4 00000000
3ffffa50: 3ffffc60 3ffffc60 3ffffb60 40227bc8
3ffffa60: 3ffffc60 00000001 3ffffb60 40223f23
3ffffa70: 00000000 00000000 00000001 40100874
3ffffa80: 3ffffc60 00000020 3ffffb60 00000000
3ffffa90: 3ffffc60 00000001 3ffffb60 00000000
3ffffaa0: 3ffffc60 00000001 3ffffb60 40227ef4
3ffffab0: 00000000 000b000f 00000000 00000000
3ffffac0: 73646e6f 00000000 00000000 000b000f
3ffffad0: 00000000 40101500 40101500
Incomplete stack trace saved!
<<<stack<<<
No more EEPROM space available to save crash information!
================================================================================

[+0.292s] SPIFFS: mounting SPIFFS
[+0.327s] SPIFFS: [WARNING] /config.json not found, will be created on first config save
[+0.335s] HMI: Waiting for LCD connection
[+0.582s] HMI IN: [7 bytes]: 0xff 0x00 0x00 0x00 0xff 0xff 0xff
[+0.588s] HMI: Querying LCD backlight status
[+0.593s] HMI OUT: get dim
[+0.596s] HMI IN: [4 bytes]: 0x88 0xff 0xff 0xff
[+0.601s] HMI: Nextion panel connected.
[+0.697s] HMI IN: [5 bytes]: 0x66 0x00 0xff 0xff 0xff
[+0.703s] HMI IN: [sendme Page] '0'
[+0.706s] HMI IN: [8 bytes]: 0x71 0x64 0x00 0x00 0x00 0xff 0xff 0xff
[+0.713s] HMI IN: [Int Return] '100'
[+0.716s] HMI IN: lcdBacklightDim '100'
[+0.721s] HMI OUT: bkcmd=3
[+0.724s] HMI: Querying LCD firmware version number
[+0.730s] HMI OUT: get p[0].b[2].val
[+0.734s] HMI IN: [8 bytes]: 0x71 0x02 0x00 0x00 0x00 0xff 0xff 0xff
[+0.740s] HMI IN: [Int Return] '2'
[+0.743s] HMI IN: lcdVersion '2'
[+0.747s] HMI: Querying LCD model information
[+0.752s] HMI OUT: con⸮ect
[+0.759s] HMI IN: [69 bytes]: 0x63 0x6f 0x6d 0x6f 0x6b 0x20 0x31 0x2c 0x33 0x30 0x36 0x30 0x31 0x2d 0x30 0x2c 0x4e 0x58 0x33 0x32 0x32 0x34 0x54 0x30 0x32 0x34 0x5f 0x30 0x31 0x31 0x52 0x2c 0x31 0x34 0x31 0x2c 0x36 0x31 0x34 0x38 0x38 0x2c 0x44 0x45 0x36 0x30 0x31 0x43 0x46 0x34 0x32 0x33 0x34 0x46 0x33 0x33 0x32 0x35 0x2c 0x34 0x31 0x39 0x34 0x33 0x30 0x34 0xff 0xff 0xff
[+0.814s] HMI IN: nextionModel: NX3224T024_011R
[+0.820s] HMI OUT: 'p[0].b[1].font=6'
[+2.764s] WIFI: Failed to connect to assigned AP, entering config mode
[+2.772s] HMI OUT: 'p[0].b[1].font=6'
[+2.786s] HMI OUT: 'p[0].b[1].txt=" HASP WiFi Setup\r AP: HASwitchPlate\rPassword: hasplate\r\r\r\r\r\r\r  httpr//1;2.168.4.1"'
[+2.840s] HMI OUT: vis 3,1

aderusha, 2021-11-02:
@0xJoeMartin - is this issue still present?  Did wiping and reflashing resolve the problem?

aderusha, 2021-11-10:
Closing the issue after 4 weeks.

Closed 2021-11-10.

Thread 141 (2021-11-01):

HASPOne page 7 (Alarm)

ekrotki, 2021-11-01:
Hello, I have found that automation created with blueprint for page 7 is able to arm / disarm the alarm without entering the code. More precisely saying - last entered code is used. For instance, when I do arm the alarm using correct code, it is enough to hit "disarm" to get the alarm disarmed. Obviously entering wrong code before hitting "disarm" does not do anything.
Same is for "Arming" - if the alarm was disarmed using good code, it is enough to hit "Arm" and the alarm is armed.
I feel that the code is cached / stored and not cleared after hitting the "operation button".
Can we get it cleared after hitting the action button?
Another idea - can we have several codes for few people at home? Say - per user code?
Please don't shoot if I missed something :-)

aderusha, 2021-11-02:
Well that shouldn't be happening :(

If you [take a look at the blueprint code](https://github.com/HASwitchPlate/HASPone/blob/main/Home_Assistant/blueprints/hasp_Display_Alarm_Control_page7.yaml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), what should be happening is that the current code entry should be submitted to home assistant and then immediately reset (all digits set to `-1`).

That leaves the question as to why that isn't happening for you.  Can you monitor the state of each of the `input_number.` entities while you enter the code and then select arm/disarm?  It'd be interesting to know if/how those are cycling when you perform an arm or disarm at the panel.

ekrotki, 2021-11-02:
Yes, you are right, unbelievable, but it happens. Regarding monitoring the numbers, well, what I can do is looking at "Overview" page and the numbers "alarmcode 1-6", they are filled in, shifting with each key-press, then after I hit "Arm", after some time the alarm panel shows being armed, numbers remain uncleared. For your information, I am using "manually" created alarm panel because I don't have real unit integrated, just wanted playing for the future application. This could be the factor if I did something wrong defining the "alarm panel".
I am also trying to get "kids protection" for wall plates, sometimes I do have guests with kids pushing every button in the reach of their hands... Something like "lock/unlock" the wall-plate using PIN.

ekrotki, 2021-11-07:
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

I have found that setting the number to "-1" is not allowed - tried with following call using Developer tools and failed.
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

Trying positive value it goes successfully. Now the question is how to reset the values, or how to change the validation allowing -1 at least (if not all negative values).

aderusha, 2021-11-07:
@ekrotki Have you upgraded your install to 2021.11 by chance?

ekrotki, 2021-11-07:
@aderusha Yes, I am on 2021.11

I see the lines 321,322 now allowing the values -1 up to 9 solving the problem, Code numbers are reset to -1 correctly.
Now I started thinking about binding the reset operation with state change and not just b15 button press, IMHO it would create nice feature allowing quickly revert the operation. Codw would be cleared after the delay needed for alarm to change the state.

Do you see any chance to support multiple codes? In real burglary unitwe do have at home, each user has own code granting different permissions there. Definitely it is beyond the issue (solved now) but it might be welcomed by others.
thank you for your good work !!

aderusha, 2021-11-08:
Great news, glad we got it working!

Almost everything about how the alarm system operates is dictated by the alarm device.  HASPone (with this blueprint) is simply submitting codes when entered, it's up to the alarm panel to decide what to do with them.  So, HASPone for sure supports multiple codes, which is because it doesn't actually deal with any codes at all - it's simply accumulating whatever you enter, then sending the last *n* digits to your alarm device when you press arm/disarm.

ekrotki, 2021-11-08:
@aderusha Yes, I am glad too. With apologies of posting here again - I am not yet well acquainted where I shall do it :-)
My quick solution was to use "16" instead of -1, but this is also OK.

Yes, keeping HASPone clean from "semantic" is best way to go - it shall only be the "I/O interface"  or HMI. All else is the task of something listening to MQTT.
This is why I think about implementing "screen-lock" via switching "alarm panels". Several questions are bound to this approach, but this place is not to discuss them.

Thank you for being open to cooperate !

Closed 2021-11-07.

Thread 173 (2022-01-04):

Stuck on wifi connected

scubieman, 2022-01-04:
I use to have the old haswitchplate installed on my HA. Now trying to upgrade to HASPone.

My device keeps getting stuck on WIFI connected. I tried factory resetting. Double checking names. And nothing is working. I can see if it Blueprint as device. Any ideas what issue is?

aderusha, 2022-01-04:
OK so first, make sure you [go through this process to clear out the old HASP stuff](https://github.com/HASwitchPlate/HASPone/wiki/Updating-legacy-HASP-to-HASPone).  If you're still not connecting (or things just aren't working out right for you in general), [grab a debug log](https://github.com/HASwitchPlate/HASPone/wiki/Capture-HASPone-debug-output) and post it here, then we can work through what is happening on your device and hopefully get you moving.

scubieman, 2022-01-04:
How would i delete switch plates added to HA accidently? Or Change the name? Example if i had plate01, and I switched name to brplate. It will show plate01 and brplate in list.

aderusha, 2022-01-04:
In Home Assistant, go to Configuration > Devices & Services > Devices tab > find the old device (plate01) and click on it > Delete.

scubieman, 2022-01-04:
okay they connect to wifi , but stuck on "wifi connected" and dont do anything useful

aderusha, 2022-01-04:
Allright, can you post a debug dump of the whole process?  Is this device currently in the wall?

scubieman, 2022-01-04:
its sitting next to me. I have two of them, I can not access the ip address. Generally what works is unplugging a bunch of times, but i still have some issues
want to chat on DRzz discord?

scubieman, 2022-01-05:
@aderusha So device says wifi connecting..... However I show it active in HA now. I tried running the automation HASPone Core functionality on both devices but fails to do anything
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
.

scubieman, 2022-01-05:
Lowered the serial speed down to 115200. It appears to be working now.

Closed 2022-01-05.

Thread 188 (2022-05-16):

Any way to reboot the ESP from the touchscreen?

mattster98, 2022-05-16:
I had a failure mode recently I haven't encountered before where the touch panel is working, but it is not on the network or connected to MQTT.  I eventually had to disconnect power to recover.  It came back fine - not sure what the issue was.

But, it made me realize I don't think there's any other way to force a reboot other than via MQTT.  I saw an option in the code to force a reboot when p[0].b[1] is pressed, but it's false by default.  Is something like that the best/only option?  I see you can restart the nextion lcd with a button command, but I don't think that would have helped.

I was thinking long-pressing any button for more than X seconds might be a reasonable watchdog-style reboot mechanism.  Not sure if that's possible.  Or, if the ESP can see the nextion reboot I could use that option to trigger it.

aderusha, 2022-05-16:
`rebootOnp0b1` is set `true` while the code is handling the [WiFi connection](https://github.com/HASwitchPlate/HASPone/blob/main/Arduino_Sketch/HASwitchPlate/HASwitchPlate.ino#L1962) or [MQTT connection](https://github.com/HASwitchPlate/HASPone/blob/main/Arduino_Sketch/HASwitchPlate/HASwitchPlate.ino#L326) with the intent of giving the user a chance to reboot the system during these steps if something isn't working.

A long press (or maybe "press 5 times in two seconds" or similar might be another solution that could be setup to run at all times.  I'll add this as a feature request and maybe figure something out that works a little better than the current solution.

aderusha, 2022-05-16:
Allright, added this feature to the current 1.06 development branch.  Hold any button down for 10 seconds (or more), release, and the device will trigger a reboot.

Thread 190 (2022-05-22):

All Blueprint Automations Just Stopped Working

NathanVanCleave, 2022-05-22:
All my automations that update the HASP display, such as "Core Functionality," just stopped working and the display is blank. HA logs show "Error rendering variables: UndefinedError: None has no element 0."

I have some automations in Node Red that update information on other pages via MQTT and they're all still working fine. I'm also still able to login to the device so there's no communication issue. It's just all the Blueprint automations, like the Clock, that have stopped working.

I'm running HA OS (version 8.1) on an Odroid-N2+ with core-2022.5.5. I updated to 2022.5.5 several days before this started, and updated to OS 8.1 a day or two before as well I believe. I know some users reported issues with OS 8.0, but I didn't see any similar problems at the time.

The HASP is on version 1.02, LED version 3, and ESP core version 2_7_4 and I have not tried updating anything on it yet.

I have not tried removing and setting up the blueprint automations again since I don't know why that'd help, but if someone thinks it's worth a shot I will.

NathanVanCleave, 2022-05-22:
Never mind!

I just downloaded the newer "Core functionality" blueprint (I think I had 1.02 or something instead of 1.05 because there was a new "Maximize HASPone Performance" option I didn't have before) and it's working again!

I should have tried just turning on the "First-time HASPone setup or rest" before reimporting the blueprint, but either way it's back. I should also have tried this before opening an issue, but maybe someone else will come across this as well.

Closed 2022-05-22.

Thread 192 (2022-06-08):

Screen has no display but still responding to touch

mattster98, 2022-06-08:
I moved the unit into a new triple cover plate.  It was a little snug to get the display into the plate but nothing crazy.  After reassembling and powering up the system is up, on network, responding to touch, but nothing on the display other than backlight.

Wondering if there is any troubleshooting for what I may have broken or just need to replace the display.

aderusha, 2022-06-16:
Your best bet will be to pull the thing open, remove the PCB from the mount to pull the board out of the rear enclosure, and then hook up to the USB port.  This will let you grab some debug logs that should tell you what is going on: https://github.com/HASwitchPlate/HASPone/wiki/Capture-HASPone-debug-output

If you can post the log results somewhere where we can take a look, we might be able to work out a solution together.

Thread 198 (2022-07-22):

Errors with Blueprints

omayhemo, 2022-07-22:
After my system was shut down for some time, all the HASPone I have in the house, blanked their display back to the basic core configuration.  I've attempted running the BPs again, even going back and running the core configuration BP, but I get errors whenever I run them.  I also get the following error on HA startup.  So all my HASPone are currently not programmable.  I'm on the latest Blueprint Version: 1.05.00 for everything.

The following error on HA startup:
```
2022-07-22 08:13:32 ERROR (MainThread) [homeassistant.components.automation] Blueprint HASPone p[x].b[y] displays a toggle button generated invalid automation with inputs OrderedDict([('ycen_select', '1 - Centered'), ('haspdevice', '6d4c8c9161af143210a835cdf66845ee'), ('entity', 'input_boolean.master_bedroom_automation'), ('state_on', 'on'), ('text_on', '||'), ('text_off', '>'), ('on_fgcolor', 0), ('off_bgcolor', 0), ('off_fgcolor', 0), ('action_on', [OrderedDict([('service', '')])]), ('action_off', [OrderedDict([('service', '')])]), ('xcen_select', '1 - Centered'), ('hasppage', 10), ('font_select', '8 - Noto Sans 64'), ('haspbutton', 7), ('on_bgcolor', 0)]): Service  does not match format <domain>.<name> for dictionary value @ data['action'][0]['choose'][2]['sequence'][0]['choose'][0]['sequence'][0]['choose'][0]['sequence'][0]['service']. Got None
```

The following error when I run any BP:
```
2022-07-22 08:21:23 ERROR (MainThread) [homeassistant.components.automation.hasp_master_p10b1_displays_a_toggle_button] Error rendering variables: UndefinedError: None has no element 0
```

The following error intermittently (about every 30sec):
```
2022-07-22 08:22:46 ERROR (MainThread) [homeassistant.components.automation.hasp_p1b3_displays_a_toggle_button] Error rendering variables: UndefinedError: None has no element 0
```

aderusha, 2022-07-22:
It looks like you don't have anything entered for the "action on" part of the blueprint.  If you go into the editor, I suspect you'll find that "Service" has been selected but no actual service call configured.  It's failing trying to execute that empty service call.

omayhemo, 2022-07-22:
The action is filled out on all the BP automations.
Example:
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

omayhemo, 2022-07-22:
Built a new automation from BP from scratch just to be sure (just to be clear, nothing has changed in these automations since they were working that I'm aware of).  Still the same error.  Both off and on actions were fully filled out.

Simplified with a group, didn't help.
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

aderusha, 2022-07-22:
Can you post the trace from running the automation?

omayhemo, 2022-07-22:
Let me know if this is what you're looking for.  HASPone is the only thing I use HA automations for (prefer NetDaemon), so not real familiar with debugging them.

```
{
  "trace": {
    "last_step": null,
    "run_id": "7b605e4157c5c148efb105e611ac3100",
    "state": "stopped",
    "script_execution": null,
    "timestamp": {
      "start": "2022-07-22T15:02:03.296829+00:00",
      "finish": "2022-07-22T15:02:03.305029+00:00"
    },
    "domain": "automation",
    "item_id": "1658500814791",
    "error": "UndefinedError: None has no element 0",
    "trigger": null,
    "trace": {},
    "config": {
      "mode": "parallel",
      "max_exceeded": "silent",
      "variables": {
        "haspdevice": "6d4c8c9161af143210a835cdf66845ee",
        "haspname": "{%- for entity in device_entities(haspdevice) -%}\n  {%- if entity|regex_search(\"^sensor\\..+_sensor(?:_\\d+|)$\") -%}\n    {{- entity|regex_replace(find=\"^sensor\\.\", replace=\"\", ignorecase=true)|regex_replace(find=\"_sensor(?:_\\d+|)$\", replace=\"\", ignorecase=true) -}}\n  {%- endif -%}\n{%- endfor -%}",
        "hasppage": 10,
        "haspbutton": 8,
        "entity": "light.master_lamps_2",
        "attribute": "state",
        "state_on": "on",
        "action_on": [
          {
            "service": "light.turn_on",
            "data": {},
            "target": {
              "entity_id": "light.master_lamps_2"
            }
          }
        ],
        "action_off": [
          {
            "service": "light.turn_off",
            "data": {},
            "target": {
              "entity_id": "light.master_lamps_2"
            }
          }
        ],
        "text_on": "Turn Off",
        "text_off": "Turn On",
        "on_fgcolor": -1,
        "on_bgcolor": -1,
        "off_fgcolor": -1,
        "off_bgcolor": -1,
        "font_select": "8 - Noto Sans 64",
        "font": "{{ font_select.split(\" - \")[0] | int }}",
        "xcen_select": "1 - Centered",
        "xcen": "{{ xcen_select.split(\" - \")[0] | int }}",
        "ycen_select": "1 - Centered",
        "ycen": "{{ ycen_select.split(\" - \")[0] | int }}",
        "wrap": false,
        "haspobject": "{{ \"p[\" ~ hasppage ~ \"].b[\" ~ haspbutton ~ \"]\" }}",
        "commandtopic": "{{ \"hasp/\" ~ haspname ~ \"/command/\" ~ haspobject }}",
        "jsontopic": "{{ \"hasp/\" ~ haspname ~ \"/state/json\" }}",
        "jsoncommandtopic": "{{ \"hasp/\" ~ haspname ~ \"/command/json\" }}",
        "isbr": "{% if wrap == true %}1{% else %}0{% endif %}",
        "selectedfgtopic": "{{ \"hasp/\" ~ haspname ~ \"/light/selectedforegroundcolor/rgb\" }}",
        "selectedbgtopic": "{{ \"hasp/\" ~ haspname ~ \"/light/selectedbackgroundcolor/rgb\" }}",
        "unselectedfgtopic": "{{ \"hasp/\" ~ haspname ~ \"/light/unselectedforegroundcolor/rgb\" }}",
        "unselectedbgtopic": "{{ \"hasp/\" ~ haspname ~ \"/light/unselectedbackgroundcolor/rgb\" }}",
        "selectedfg": "{%- set color = namespace() -%} {%- for entity in device_entities(haspdevice) -%}\n  {%- if entity|regex_search(\"^light\\..*_selected_foreground_color(?:_\\d+|)$\") -%}\n    {%- set color.source=entity -%}\n  {%- endif -%}\n{%- endfor -%} {%- set brightness = state_attr(color.source, \"brightness\")|int(default=255) / 255 -%} {%- set red=(state_attr(color.source, \"rgb_color\")[0] * brightness)|int(default=0) -%} {%- set green=(state_attr(color.source, \"rgb_color\")[1] * brightness)|int(default=0) -%} {%- set blue=(state_attr(color.source, \"rgb_color\")[2] * brightness)|int(default=0) -%} {{ (red|bitwise_and(248)*256) + (green|bitwise_and(252)*8) + (blue|bitwise_and(248)/8)|int }}",
        "selectedbg": "{%- set color = namespace() -%} {%- for entity in device_entities(haspdevice) -%}\n  {%- if entity|regex_search(\"^light\\..*_selected_background_color(?:_\\d+|)$\") -%}\n    {%- set color.source=entity -%}\n  {%- endif -%}\n{%- endfor -%} {%- set brightness = state_attr(color.source, \"brightness\")|int(default=255) / 255 -%} {%- set red=(state_attr(color.source, \"rgb_color\")[0] * brightness)|int(default=0) -%} {%- set green=(state_attr(color.source, \"rgb_color\")[1] * brightness)|int(default=0) -%} {%- set blue=(state_attr(color.source, \"rgb_color\")[2] * brightness)|int(default=0) -%} {{ (red|bitwise_and(248)*256) + (green|bitwise_and(252)*8) + (blue|bitwise_and(248)/8)|int }}",
        "unselectedfg": "{%- set color = namespace() -%} {%- for entity in device_entities(haspdevice) -%}\n  {%- if entity|regex_search(\"^light\\..*_unselected_foreground_color(?:_\\d+|)$\") -%}\n    {%- set color.source=entity -%}\n  {%- endif -%}\n{%- endfor -%} {%- set brightness = state_attr(color.source, \"brightness\")|int(default=255) / 255 -%} {%- set red=(state_attr(color.source, \"rgb_color\")[0] * brightness)|int(default=0) -%} {%- set green=(state_attr(color.source, \"rgb_color\")[1] * brightness)|int(default=0) -%} {%- set blue=(state_attr(color.source, \"rgb_color\")[2] * brightness)|int(default=0) -%} {{ (red|bitwise_and(248)*256) + (green|bitwise_and(252)*8) + (blue|bitwise_and(248)/8)|int }}",
        "unselectedbg": "{%- set color = namespace() -%} {%- for entity in device_entities(haspdevice) -%}\n  {%- if entity|regex_search(\"^light\\..*_unselected_background_color(?:_\\d+|)$\") -%}\n    {%- set color.source=entity -%}\n  {%- endif -%}\n{%- endfor -%} {%- set brightness = state_attr(color.source, \"brightness\")|int(default=255) / 255 -%} {%- set red=(state_attr(color.source, \"rgb_color\")[0] * brightness)|int(default=0) -%} {%- set green=(state_attr(color.source, \"rgb_color\")[1] * brightness)|int(default=0) -%} {%- set blue=(state_attr(color.source, \"rgb_color\")[2] * brightness)|int(default=0) -%} {{ (red|bitwise_and(248)*256) + (green|bitwise_and(252)*8) + (blue|bitwise_and(248)/8)|int }}",
        "entity_attribute": "{% if attribute|lower == \"state\" %}{{states(entity)}}{% else %}{{state_attr(entity,attribute)}}{% endif %}",
        "entity_state": "{% if entity_attribute|lower == state_on %}{{true}}{% else %}{{false}}{% endif %}",
        "toggle_selectedfg": "{% if entity_state %}{% if on_fgcolor|int >= 0 %}{{on_fgcolor}}{% else %}{{selectedfg}}{% endif %}{% else %}{% if off_fgcolor|int >= 0 %}{{off_fgcolor}}{% else %}{{unselectedfg}}{% endif %}{% endif %}",
        "toggle_selectedbg": "{% if entity_state %}{% if on_bgcolor|int >= 0 %}{{on_bgcolor}}{% else %}{{selectedbg}}{% endif %}{% else %}{% if off_bgcolor|int >= 0 %}{{off_bgcolor}}{% else %}{{unselectedbg}}{% endif %}{% endif %}",
        "toggle_unselectedfg": "{% if not entity_state %}{% if on_fgcolor|int >= 0 %}{{on_fgcolor}}{% else %}{{selectedfg}}{% endif %}{% else %}{% if off_fgcolor|int >= 0 %}{{off_fgcolor}}{% else %}{{unselectedfg}}{% endif %}{% endif %}",
        "toggle_unselectedbg": "{% if not entity_state %}{% if on_bgcolor|int >= 0 %}{{on_bgcolor}}{% else %}{{selectedbg}}{% endif %}{% else %}{% if off_bgcolor|int >= 0 %}{{off_bgcolor}}{% else %}{{unselectedbg}}{% endif %}{% endif %}",
        "text": "{% if entity_state %}{{text_on}}{% else %}{{text_off}}{% endif %}",
        "button_trigger": "ON"
      },
      "trigger_variables": {
        "haspdevice": "6d4c8c9161af143210a835cdf66845ee",
        "haspname": "{%- for entity in device_entities(haspdevice) -%}\n  {%- if entity|regex_search(\"^sensor\\..+_sensor(?:_\\d+|)$\") -%}\n    {{- entity|regex_replace(find=\"^sensor\\.\", replace=\"\", ignorecase=true)|regex_replace(find=\"_sensor(?:_\\d+|)$\", replace=\"\", ignorecase=true) -}}\n  {%- endif -%}\n{%- endfor -%}",
        "haspsensor": "{%- for entity in device_entities(haspdevice) -%}\n  {%- if entity|regex_search(\"^sensor\\..+_sensor(?:_\\d+|)$\") -%}\n    {{ entity }}\n  {%- endif -%}\n{%- endfor -%}",
        "jsontopic": "{{ \"hasp/\" ~ haspname ~ \"/state/json\" }}",
        "hasppage": 10,
        "haspbutton": 8,
        "haspobject": "{{ \"p[\" ~ hasppage ~ \"].b[\" ~ haspbutton ~ \"]\" }}",
        "buttonjsonpayload": "{\"event_type\":\"button_short_press\",\"event\":\"{{haspobject}}\",\"value\":\"ON\"}",
        "selectedfgtopic": "{{ \"hasp/\" ~ haspname ~ \"/light/selectedforegroundcolor/rgb\" }}",
        "selectedbgtopic": "{{ \"hasp/\" ~ haspname ~ \"/light/selectedbackgroundcolor/rgb\" }}",
        "unselectedfgtopic": "{{ \"hasp/\" ~ haspname ~ \"/light/unselectedforegroundcolor/rgb\" }}",
        "unselectedbgtopic": "{{ \"hasp/\" ~ haspname ~ \"/light/unselectedbackgroundcolor/rgb\" }}"
      },
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
aderusha, 2022-07-22:
Huh.  I'm trying to piece these together as we're looking at logs from several different automations.  Taking the most recent post with the full log "Master HASPone - Lamps", I notice that the path is `HASwitchPlate/hasp_Display_Toggle 2.yaml` and I'm curious about the ` 2` part there.  Would it be possible to clean house (nuke automations, clear out `blueprints/HASwitchPlate` and re-import) or would that be a huge undertaking?

Also, can you show me what Home Assistant logs in the main system log when you fire off the "Master HASPone - Lamps" automation?

omayhemo, 2022-07-22:
I have no idea what that path is from, other than I create directly from BP and then rename and configure.  I didn't mess around with the yaml.

While not optimal, I will try clearing everything and starting from scratch.  It's not trivial, but it's not huge either.

Closed 2022-08-16.

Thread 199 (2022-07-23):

Temperature blueprint - doesn't save

SteveRMann, 2022-07-23:
First noticed when I keep turning this option off, but it won't save.  In fact, turning the option off does not prompt for "save". I have to change something else to get the save button.  But it doesn't save the automation.
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

Further, I deleted the automation and the blueprint, then downloaded the blueprint again, clicked on create automation, clicked on save. And there was no "run automations" at the top of the blueprint.  And there is no automation saved in "Automations".

Tried is on a different device. Create the temperature button, click on save then run actions. Works fine. Open the automation and turn on the colorize option, click "save" then - nothing.  The "run automations" button did not appear and the saved automation

SteveRMann, 2022-07-23:
Update-
I opened automations.yaml and found three copies of the automation:

`- id: '1658588868806'
  alias: desktop - HASP current temperature
  description: ''
  use_blueprint:
    path: HASwitchPlate/hasp_Display_Weather_Temperature_with_Icon_and_Colors.yaml
    input:
      haspdevice: abdbcdf0fb55720ab6b413e4fe8f7720
      suffix_select: °F
- id: '1658589448746'
  alias: desktop - HASP Current Temperature
  description: ''
  use_blueprint:
    path: HASwitchPlate/hasp_Display_Weather_Temperature_with_Icon_and_Colors.yaml
    input:
      haspdevice: abdbcdf0fb55720ab6b413e4fe8f7720
      suffix_select: °F
      roundtemp: true
- id: '1658589610897'
  alias: desktop - HASP Current Temperature
  description: ''
  use_blueprint:
    path: HASwitchPlate/hasp_Display_Weather_Temperature_with_Icon_and_Colors.yaml
    input:
      haspdevice: abdbcdf0fb55720ab6b413e4fe8f7720
      haspbutton: 6
      weather_provider: weather.openweathermap
      suffix_select: °F
      roundtemp: true
`

That doesn't seem right.

aderusha, 2022-07-23:
You are very likely running into [this bug in Home Assistant](https://github.com/home-assistant/frontend/issues/13206).  Responding to that bug or adding a "thumbs up" might help get some visibility on the issue.

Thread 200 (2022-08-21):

Won't Stay Connected

omayhemo, 2022-08-21:
This is the first HASPone I installed.  It's no longer staying connected and constantly reboots to the QR code.  Most of the time sits on connecting to Wi-Fi.  I've tried setting it up with the BPs again, but it's hard to keep online, usually crashes and heads back to the Wi-Fi connecting screen or QR code.

I've attempted to follow these instructions https://github.com/HASwitchPlate/HASPone/wiki/Flashing-HASPone-to-an-ESP8266
that I found recommended for a similar now closed issue, but when I plug it into the computer it never registers a port, the blue light on the ESP lights briefly then goes out and no further activity.  Seems like it maybe bricked.

omayhemo, 2022-08-27:
Still won't connect to the wifi, I'm assuming the ESP wifi is bricked.

aderusha, 2022-08-27:
Any chance you have a debug log to share to see if the device is trying to tell us something?  Does moving the device physically result in a different outcome?  Trying to figure out if we're seeing a signal issue or code issue or a failed ESP8266.  I've yet to see just the WiFi fail, but hey there's a first time for everything maybe?

omayhemo, 2022-08-27:
I have 4 UniFi APs in my home.  One of them is within 15' of the HASP, I've tuned my WiFi by measuring every corner of my home because I'm obsessive like that, signal strength is definitely not a problem.  You may (or probably not) remember I recently had a problem with a rogue automation that was preventing me from using the BPs to program things.  You suggested I reset.  I did that.  That's when it started dropping offline intermittently.  So I flashed it.

I can't get the HASP online at all anymore, since I flashed it, so I don't believe I can provide a debug log.  At this time, it's sitting at the QR code (and has been since flash), and I cannot connect to it's internal AP, so I can't do anything with it.

aderusha, 2022-08-27:
If the device is showing the QR code then it's alive in some sense and should be spitting out debug logs via serial while doing so.  I don't want to have you running in too many circles here, so if you'd like to setup a return, hit me up at luma@svideo.org and we can get that worked out that way.

Otherwise, getting a serial debug log will require disassembling the device.  Another alternative is to try out the latest dev build of 1.06 which has several fixes around the wifi stack that has improved connection performance for my devices here where I also have 4 Unifi APs.  That can be flashed using the process you linked above and you can find that build here: https://github.com/HASwitchPlate/HASPone/raw/dev-1.06/Arduino_Sketch/HASwitchPlate.ino.d1_mini.bin

omayhemo, 2022-08-31:
I'll try flashing 1.06 and see if I can get the logs too, will be a useful exercise for me.

ssurovich, 2022-09-06:
I flashed 1.06 and it just sends my panel into an endless loop of Connecting to WiFi and you can see the initial screen with my buttons but then it reboots - endless loop of this.

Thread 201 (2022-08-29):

Getting an error when trying to flash the Nextion display using an SD Card - File Version is too low

rkhanso, 2022-08-29:
Getting an error when using putting the FAT-32 formatted micro SD Card in the Nextion display and booting it - File Version is too low
Is this a problem with the HASwitchPlate.tft  that I downloaded? Something else?

rkhanso, 2022-08-29:
Someone from the Nextion forum said the following.

Apparently, the firmware of your Nextion is more recent than the editor version used to compile the tft file. That’s not a SD card problem. That’s because the one who created the tft file did compile it a long time ago and/or using a now outdated editor version.

If I were you, I’d ask the guy to simply recompile it from his .hmi source with the current editor 1.63.1 for you and other users who purchased their screens recently. Or I’d download and install the current Nextion Editor myself, load the .hmi file from GitHub and recompile it.

aderusha, 2022-08-29:
The HASPone project has two firmware images, one for the ESP8266 and one for the Nextion display.  The program `NodeMCU-PyFlasher` can be used to flash an ESP8266 with the ESP8266 firmware file found [here](https://github.com/HASwitchPlate/HASPone/blob/main/Arduino_Sketch/HASwitchPlate.ino.d1_mini.bin).

`HASwitchPlate.tft` is the Nextion firmware, which you can apply to the Nextion through the HASPone web interface of via an SDcard.  If you want to open the Nextion project in the Nextion editor, the file [HASwitchPlate.HMI](https://github.com/HASwitchPlate/HASPone/blob/main/Nextion_HMI/HASwitchPlate.HMI) is the source document for this project and can be edited as needed.

Make sense?  It seems your core problem is attempting to load a Nextion firmware into an ESP8266 firmware flashing tool, which isn't going to work out.

rkhanso, 2022-08-30:
I'm pretty sure I'm trying this correctly. I'm not trying to put the ESP8266 firmware on the Nextion display.  I see where I made a mistake in my intitial comment and title. That was definitely a mistake. It should NOT have said using NodeMCU-PyFlasher. I'm sorry for the confusion.  I'll see if I can change it.

I have an 8GB Micro SD Card that I formatted with FAT-32.  I copied HASwitchPlate.tft onto the SD Card and inserted it into the Nextion Display's slot and then booted it up. I get the error about the File Version being too low.

aderusha, 2022-08-30:
Huh.  That is pretty unexpected, I have a batch of Nextion devices that I received last week from ITEAD that are all flashing with the current revision, that was generated on 1.61.  1.63 has some changes that result in even less available memory on the device and, as a result, the current project cannot compile.  It is possible to go and make some changes to the project to remove some fields etc to free up additional memory, but you'd be running a version of the firmware that is slightly less capable than the code that's in the project.

Here's a thought - can you launch the upgrade from the HASPone web interface and see what it does?  The good news with Nextion is that they're nearly impossible to brick, so trying a firmware flash that goes sideways shouldn't leave you in a state that you cannot recover from.

rkhanso, 2022-08-30:
I guess some people have had trouble with certain SD Cards. I use the generic MicroCenter SD Cards. Maybe I need to get name-brand instead.

Question about the pins to connect the wires between Nextion and 8266. Blue and Yellow wires go to which Pins on the D1 Mini/8266?   I've seen references to the Tx and Rx pins on the 8266, and also D4 and D7.

rkhanso, 2022-08-30:
Nevermind. I got it connected. D7 and D4.
But I'm not sure how to do an upgrade/update to get the Nextion file on it. Won't I just be updating the ESP/HASPone firmware?

rkhanso, 2022-08-30:
Boy - I feel stupid. I just messed around a little more and figured out what you were talking about.

But I get the same error:   File Version is too low

So I guess it's probably not the SD Card that's the problem then.

rkhanso, 2022-08-30:
The Nextion display I just received from Amazon was from your link on Github. It has NX3224T024_011 on the back. There's a sticker over the SD Card Slot that says DE607C43435D5236. On the edge of the display it has HST024042 3-2.

Since I'm getting the "File Version is too low" when trying both the SDCard and ESP8266 method of installing the HASwitchPlate.tft file, do you think I'm doing everything correct and there is some other issue that is going on? Something that can be fixed? Or should I return the display to Amazon?  I'd really like to get this HASPone working since I've spent this money on it.

rkhanso, 2022-08-30:
I think I got it. I hope I didn't mess anything up though....
The Nextion Editor seemed to indicate to me that the only problem was p0.
That appears to be a QR code to use with your phone to set up WiFi with the HASPone. There was a gray rectangle in front of the QR code. I clicked it and hit delete. I then compiled, put that file on an SD Card and uploaded it to the display. It sayd Update Successful!

Powered it up and it connected to WiFi. MQTT is connected.  I think I just need to go through the Home Assistant setup now, right?

aderusha, 2022-08-30:
The editor will fail to compile because the project runs out of memory after recent updates which reduce the overall memory available.  It told you about p0 because that's the first page, but in general, one just needs to remove something from the overall project.  You've removed the QR code which means you won't see the code during the initial setup process, but otherwise everything should work as normal.

Now run through the setup!

djqpaz, 2022-09-04:
[rkhanso](https://github.com/rkhanso) any update? i just recently kicked off this as a project.  Seem as though there is a problem with the incompatibility with newer firmware and older tft files for the screen.

I ordered a USB to TTL to try and touble shoot, but not sure what to do next.

rkhanso, 2022-09-05:
I got it to work by removing a gray rectangle on the p0 page. After I did that, I could install the firmware since the size was a little bit smaller. The only thing that affects is showing the p0 page (QR code) - but the display still shows the IP address/SSID....so no trouble in the end. You don't really need the p0 page to get it set up.

A little more info - in the Nextion Editor, load the .hmi.  On page p0, click on the gray rectangle over the QR code area and delete it. Then you can compile successfully and put it on the the SD Card and update the display like normal using the SD Card method.

aderusha, 2022-09-05:
I've just updated the main project branch with a new HMI and TFT file for the Nextion Basic to address this issue.  Removing components will get the job done but will make your project incompatible with some blueprints.

As no new features are added and this only impacts the Basic model, I've not incremented the version in the project as I don't want people being lit up with an update notification.  So, LCD version stays at 3, but if you are having problems getting it loaded on a new Nextion device, try re-downloading the link from the repo and trying again (via web upload, SD card, etc).

Closed 2022-11-10.

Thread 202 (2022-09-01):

Alternate LCD Ground and RX Points?

ssurovich, 2022-09-01:
Hate to ask - but I had a little too much heat when I took the original connector off the LCD PCB and I lost the pads for the Ground and Receive pins - I followed the traces on the board and I think I have alternate points, but before I tried them, I was hoping someone may be able to verify any alternate points for GND and RX?

Thanks!

ssurovich, 2022-09-06:
Closing, I bought a new panel so I could find the pinouts and found a few spots I could use and the original panel is all good now.

Closed 2022-09-06.

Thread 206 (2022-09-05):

Trouble locating small quantities of threaded inserts and screws

rkhanso, 2022-09-05:
Yes, this is not an issue with the hardware or software of the HASPone device itself. I'm near the end of the build and am striking out finding the threaded inserts and matching screws. The Amazon link on the Github page for the threaded inserts shows they are unavailable. I've checked Fastenal and don't find any M2 inserts. They don't seem to have any standard/US sizes that small either. I'd rather not buy in bulk since I only need 4 of them.

Is there a decent alternative for the hardware or other options for assembling the case?

aderusha, 2022-09-06:
Hey thanks for the head's up! I've gone and updated the BOM to point to suitable components which (as of this writing) are currently in stock.  [Here are the inserts you'll be needing](https://www.amazon.com/uxcell-Knurled-Threaded-Insert-Embedment/dp/B07LBQFNQD/).

Single quantities are going to be more difficult, the economics of selling small parts is such that the price of the part is a small faction of the price of selling the part (amazon fees, shipping, etc).  You might find a seller that's only selling a few of the things, but the price isn't likely to be very different as the platform/shipping/etc fees don't go much lower than whatever it already costs to ship 100 tiny brass inserts.

Closed 2022-11-10.

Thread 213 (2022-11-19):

Dimmer slider issues

Gurulu-pc, 2022-11-19:
Might be my configurations but when I slide the dimmer in home assistant, my HASPone slider moves accordingly and the light obeys. When i move the slider on the HASPone, nothing happens. So basically, the HASPone slider is only a status indicator instead of a control device. The dimmer is a DIY lamp I've built with esphome and a led strip. It's very strait forward PWM dimming from a wemo D1 mini. The dimmer was configured from the default blueprint from this repo (hasp_Display_Dimmer_with_Icon.yaml)
Software version : Home Assistant 2022.11.3, Supervisor 2022.10.2, Operating System 9.3
hardware: RPI3B+
here's the relevant automation.yaml entry :
`- id: '1667772236417'
  alias: HASPone p[x].b[y] displays a dimmer with a toggle on/off icon
  description: ''
  use_blueprint:
    path: HASwitchPlate/hasp_Display_Dimmer_with_Icon.yaml
    input:
      font_select: 6 - Noto Sans 32
      haspdevice: 43f87b51c35fe9a31c395bb715839774
      haspbutton: 8
      dimmer: light.salle_de_bain
      text_on: Lum Pharmacie |
      ycen_select: 1 - Centered
      icon_off: 
      icon_on: 
      xcen_select: 2 - Right aligned
      hasppage: 4
`
Thanks for your help

aderusha, 2022-11-20:
What happens when you move the slider on the HASPone?  Does the slider move and stay where you dragged it on the display?

If you look at device `light.salle_de_bain` in Home Assistant when you do this, does the brightness change in HA at all?  What happens if you change the brightness in HA, do you see any change on the slider on your HASPone?

Gurulu-pc, 2022-11-20:
> What happens when you move the slider on the HASPone? Does the slider move and stay where you dragged it on the display?

Yes, slider moves and stay where it was dragged.
> If you look at device `light.salle_de_bain` in Home Assistant when you do this, does the brightness change in HA at all?

No, nothing changes on HA's side.

> What happens if you change the brightness in HA, do you see any change on the slider on your HASPone?

Yes, HASPone slider moves accordingly and stay in the position of the new brightness value.

Also, my mqtt server is hosted by another machine. I don't know if this is relevant to the issue. Doesn't seem like it should be a problem at all but could be. I'm not running firewall on my local network.

aderusha, 2022-11-20:
Do you get anything in the automation log when you drag the slider?

Gurulu-pc, 2022-11-24:
Nothing happens in the logs and mqtt server is not receiving anything. I did tweak the nexion interface to my liking. I'll compare the default tft file from the repo and mine just to be sure.

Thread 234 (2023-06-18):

Blueprint for Heatpump (both Pge6 and Pge9) are not working HA 2023.6.x

austwhite, 2023-06-18:
Hi,
It seems the blueprint for the Heatpump control, both Page 6 and Page 9 versions fail in HA 2023.6.x.   Well, at least for me it does.
The automation will run initially and the page display on the HASPOne device.   I can then press Heat and change the temperature, but when I hit Off it completely freezes up and never runs the automation again.     I can delete and recreate the automation, and Home Assistant reports it is never running.   If I wait several hours, then it might run again, but the same thing as above happens.   It will stop running when the Off button is used and then the automation stops running again
This happens with both the Page 6 and Page 9 versions.

This is not a critical thing, as I can use different options to control HVAC systems, it would just be a nice to have on the HASPOne :)

Thanks :)

austwhite, 2023-06-21:
As an additional comment.  The issue seems to happen when "off" is selected and the automation doesn't run when the HVAC is in "off" mode" .  If I set the HVAC to Heat or Cool mode, then the automation resumes running and I can control everything from the HASPOne.   As soon as the HVAC is switched to OFF, the automation stops running again.
Happens with both Pge6 and Pge9 versions, so looks to be something when climate.xxxx is in the "off" mode.

BenJewell, 2024-08-26:
Did you ever find a solution for this?

austwhite, 2024-10-26:
No soloution found for this.  Will have to wait for th developer to look at it I think.

austwhite, 2024-12-29:
Looks like these work fine with the Generic Thermostate now, though there is no way to tell the blueprint it is heat only or cool only, so it still displays the heat cool button.
Still completely not working with Z-Wave thermostat, so much so that the automation doesn't even run when a Z-Wave thermostat is selected.

Closed 2025-07-26.

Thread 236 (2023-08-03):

Mqtt issue with new HA 2023.8.0

farberm, 2023-08-03:
Some MQTT entities have an entity name that starts with the device name. This is not expected. To avoid a duplicate name the device name prefix is stripped of the entity name as a work-a-round. Please inform the maintainer of the software application that supplies the affected entities to fix this issue.

List of affected entities:

light.plate01_backlight
light.front_porch_light_button_c
number.plate01_active_page
light.front_porch_light_button_d
light.plate01_selected_foreground_color
light.plate01_unselected_foreground_color
sensor.plate01_sensor
light.plate01_selected_background_color
light.front_porch_light_button_b
light.plate01_unselected_background_color
light.front_porch_light_button_a

aderusha, 2023-08-03:
Sounds like a new breaking change in Home Assistant which conveniently isn't mentioned in the breaking changes.  Sounds like we have 6 months to address this and the errors can be ignored for the moment.  I'm digging into this and will get a solution ready ASAP.

Forum thread on the topic here: https://community.home-assistant.io/t/psa-mqtt-name-changes-in-2023-8

farberm, 2023-08-03:
ThxSent from my iPadOn Aug 3, 2023, at 1:40 AM, Allen Derusha ***@***.***> wrote:
Sounds like a new breaking change in Home Assistant which conveniently isn't mentioned in the breaking changes.  Sounds like we have 6 months to address this and the errors can be ignored for the moment.  I'm digging into this and will get a solution ready ASAP.
Forum thread on the topic here: https://community.home-assistant.io/t/psa-mqtt-name-changes-in-2023-8

—Reply to this email directly, view it on GitHub, or unsubscribe.You are receiving this because you authored the thread.Message ID: ***@***.***>

austwhite, 2023-08-04:
This is a new change to clean up MQTT entities in Home Assistant.
Same error here, and I also get errors on my ESPPresense devices (different project of course).

Looks like all the blueprints and MQTT entities will need to be updated to match the new MQTT naming conventions

lebherz, 2023-09-28:
hey @aderusha
any idea to fix it? or should we leave this project 👎

aderusha, 2023-09-28:
A firmware update is being worked on for this and a couple other changes.  It will also require a blueprint update.  You should no longer be seeing notifications on the problem after the HA devs backed off on the panic button.  We have 6 months so I'm going to use this time to see if a few more things can't make their way into the change too.

So no need to worry yet, I have these things all over my house and use them constantly and so I'm going to keep this going. My house would be a lot dumber without HASPone.

aderusha, 2024-07-24:
1.06 addresses this issue with the new MQTT discovery format.

Closed 2024-07-24.

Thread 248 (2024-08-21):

Need to Reset HASPone

stuartdhii, 2024-08-21:
Screen boots to: WIFI Connected!
                             IP:192.168.50.95

                             Configure MQTT:
                             http://192.169.50.95

I cannot access the setup screen and need to reset the device.  I even tried static setting for Homeassistant at this address to try and bring up MQTT and it then rebooted with another assigned ip address for both the device and MQTT.

I purchased the unit build from you a few months ago and am now trying to bring it up. Let me know what I can do to reset.

Thanks,  Stuart

BenJewell, 2024-08-26:
Oh wow, I am having the exact same issue, and I also purchased mine a few months ago and just started setting it up! Spent an hour messing around with it and thought I was crazy. I wounder if there was a specific batch that ours were both part of that they flashed with bad firmware.

Pretty silly that they built this with no physical reset button. We both paid a premium buying it pre-assembled and now it looks like we are going to have to learn how to flash it anyway. :(

aderusha, 2024-08-26:
Hey there!  OK so one thing that might help right away would be to turn off your WiFi in your house, reset the HASPone, then let it go into setup mode when it cannot connect to WiFi.

Annoyingly, the next step would in fact be to take the device apart and run a factory reset if it's still not accessible.  Complete instructions can be found here: https://github.com/HASwitchPlate/HASPone/wiki/Flashing-HASPone-to-an-ESP8266

stuartdhii, 2024-08-26:
There is a physical reset button but it should say reboot as it does not
reset to factory setting.

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

austwhite, 2024-10-26:
@stuartdhii
The button is a reboot, not a reset.  This only resets the the ESPdevice.  The previous instructions @aderusha  gave work.

BenJewell, 2024-11-18:
Thanks, I got it working after a couple tries. The integrated web server is really buggy and sometimes parts of the page don't load, including the required fields.

austwhite, 2025-04-22:
Just a note, remember th WeMOS D1 Mini module is a generic ESP8266 Mini module, not designed by the HaspOne project.   The "reset" button has always been a cold reboot button, not a factory reset button.  This is a design of the D1 Mini board so can't be attributed to the HASPONE project.

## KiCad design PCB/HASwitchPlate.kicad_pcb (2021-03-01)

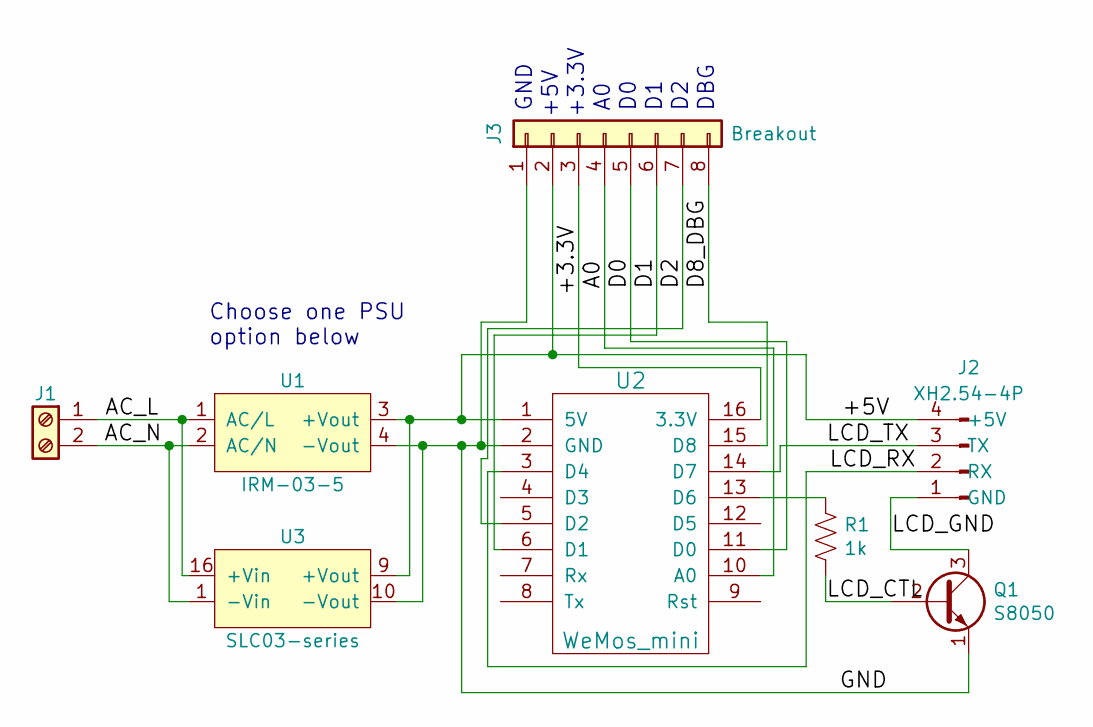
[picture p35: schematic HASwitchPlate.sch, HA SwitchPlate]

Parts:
J1: Screw Term.; TerminalBlock_bornier-2_P5.08mm
J2: XH2.54-4P; JST_XH2.54_04x2.54mm_Straight
J3: Breakout; Pin_Header_Straight_1x08_Pitch2.54mm
Q1: S8050; TO-92L_HandSolder
R1: 1k; R_Axial_DIN0207_L6.3mm_D2.5mm_P7.62mm_Horizontal
U1: IRM-03-5; ACDC-Converter_MeanWell-IRM-03-x
U2: WeMos_mini; wemos-d1-mini-with-pin-header-and-connector
U3: SLC03-series; ACDC-Converter_MeanWell-SLC03-series

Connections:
/+3.3V: J3.3, U2.16 (3.3V)
/+5V: J2.4 (+5V), J3.2, U1.3 (+Vout), U2.1 (5V), U3.9 (+Vout)
/A0: J3.4, U2.10 (A0)
/AC_L: J1.1, U1.1 (AC/L), U3.16 (+Vin)
/AC_N: J1.2, U1.2 (AC/N), U3.1 (-Vin)
/D0: J3.5, U2.11 (D0)
/D1: J3.6, U2.6 (D1)
/D2: J3.7, U2.5 (D2)
/D8_DBG: J3.8, U2.15 (D8)
/GND: J3.1, Q1.1 (E), U1.4 (-Vout), U2.2 (GND), U3.10 (-Vout)
/LCD_CTL: Q1.2 (B), R1.2
/LCD_GND: J2.1 (GND), Q1.3 (C)
/LCD_RX: J2.2 (RX), U2.3 (D4)
/LCD_TX: J2.3 (TX), U2.14 (D7)
unnamed: R1.1, U2.13 (D6)

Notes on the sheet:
GND
+5V
+3.3V
DBG
Choose one PSU option below

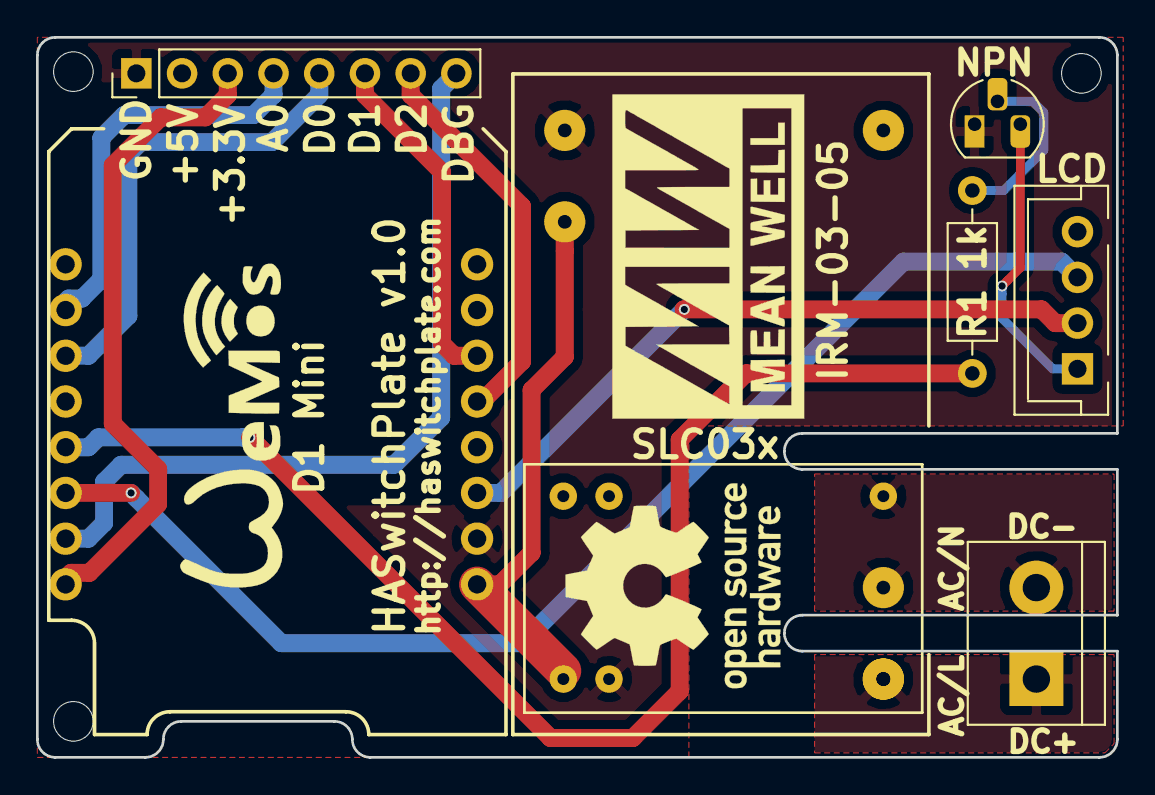
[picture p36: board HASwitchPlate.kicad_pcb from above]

Board: 2 copper layers, 60.0 x 40.0 mm, 8 parts (0 on the bottom side), 15 nets.

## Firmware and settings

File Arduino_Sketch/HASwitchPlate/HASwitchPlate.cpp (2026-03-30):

////////////////////////////////////////////////////////////////////////////////////////////////////
//           _____ _____ _____ _____
//          |  |  |  _  |   __|  _  |
//          |     |     |__   |   __|
//          |__|__|__|__|_____|__|
//        Home Automation Switch Plate
// https://github.com/aderusha/HASwitchPlate
//
// Copyright (c) 2026 Allen Derusha allen@derusha.org
//
// MIT License
//
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
#include <Arduino.h>
#include <FS.h>
#include <EEPROM.h>
#include <EspSaveCrash.h>
#include <ESP8266WiFi.h>
#include <ESP8266mDNS.h>
#include <WiFiUdp.h>
#include <ArduinoOTA.h>
#include <DNSServer.h>
#include <ESP8266HTTPClient.h>
#include <ESP8266WebServer.h>
#include <ESP8266httpUpdate.h>
#include <ESP8266HTTPUpdateServer.h>
#include <WiFiManager.h>
#include <ArduinoJson.h>
#include <MQTT.h>
#include <SoftwareSerial.h>
#include <ESP8266Ping.h>
#include <LittleFS.h>

////////////////////////////////////////////////////////////////////////////////////////////////////
// These defaults may be overwritten with values saved by the web interface
char wifiSSID[32] = "";
char wifiPass[64] = "";
char mqttServer[128] = "";
char mqttPort[6] = "1883";
char mqttUser[128] = "";
char mqttPassword[128] = "";
char mqttFingerprint[60] = "";
char haspNode[16] = "plate01";
char groupName[16] = "plates";
char hassDiscovery[128] = "homeassistant";
char configUser[32] = "admin";
char configPassword[32] = "";
char motionPinConfig[3] = "0";
char nextionBaud[7] = "115200";

////////////////////////////////////////////////////////////////////////////////////////////////////
const float haspVersion = 1.09;                       // Current HASPone software release version
const uint16_t mqttMaxPacketSize = 2048;              // Size of buffer for incoming MQTT message
byte nextionReturnBuffer[128];                        // Byte array to pass around data coming from the panel
uint8_t nextionReturnIndex = 0;                       // Index for nextionReturnBuffer
int8_t nextionActivePage = -1;                        // Track active LCD page
bool lcdConnected = false;                            // Set to true when we've heard something from the LCD
const char wifiConfigPass[9] = "hasplate";            // First-time config WPA2 password
const char wifiConfigAP[14] = "HASwitchPlate";        // First-time config SSID
bool shouldSaveConfig = false;                        // Flag to save json config to SPIFFS
bool nextionReportPage0 = false;                      // If false, don't report page 0 sendme
const unsigned long updateCheckInterval = 43200000;   // Time in msec between update checks (12 hours)
unsigned long updateCheckTimer = updateCheckInterval; // Timer for update check
unsigned long updateCheckFirstRun = 30000;            // First-run check offset
bool updateEspAvailable = false;                      // Flag for update check to report new ESP FW version
float updateEspAvailableVersion;                      // Float to hold the new ESP FW version number
bool updateLcdAvailable = false;                      // Flag for update check to report new LCD FW version
unsigned long debugTimer = 0;                         // Clock for debug performance profiling
bool debugSerialEnabled = true;                       // Enable USB serial debug output
const unsigned long debugSerialBaud = 115200;         // Desired baud rate for serial debug output
SoftwareSerial debugSerial(-1, 1);                    // -1==nc for RX, 1==TX pin
bool debugTelnetEnabled = false;                      // Enable telnet debug output
bool nextionBufferOverrun = false;                    // Set to true if an overrun error was encountered
bool nextionAckEnable = false;                        // Wait for each Nextion command to be acked before continuing
bool nextionAckReceived = false;                      // Ack was received
bool rebootOnp0b1 = false;                            // When true, reboot device on button press of p[0].b[1]
bool rebootOnLongPress = true;                        // When true, reboot device on long press of any button
unsigned long rebootOnLongPressTimer = 0;             // Clock for long press reboot timer
unsigned long rebootOnLongPressTimeout = 10000;       // Timeout value for long press reboot timer
const unsigned long nextionAckTimeout = 1000;         // Timeout to wait for an ack before throwing error
unsigned long nextionAckTimer = 0;                    // Timer to track Nextion ack
const unsigned long telnetInputMax = 128;             // Size of user input buffer for user telnet session
bool motionEnabled = false;                           // Motion sensor is enabled
bool mdnsEnabled = true;                              // mDNS enabled
bool ignoreTouchWhenOff = false;                      // Ignore touch events when backlight is off and instead send mqtt msg
bool beepEnabled = false;                             // Keypress beep enabled
unsigned long beepOnTime = 1000;                      // milliseconds of on-time for beep
unsigned long beepOffTime = 1000;                     // milliseconds of off-time for beep
unsigned int beepCounter;                             // Count the number of beeps
uint8_t beepPin = D2;                                 // define beep pin output
uint8_t motionPin = 0;                                // GPIO input pin for motion sensor if connected and enabled
bool motionActive = false;                            // Motion is being detected
const unsigned long motionLatchTimeout = 1000;        // Latch time for motion sensor
const unsigned long motionBufferTimeout = 100;        // Trigger threshold time for motion sensor
unsigned long lcdVersion = 0;                         // Int to hold current LCD FW version number
unsigned long updateLcdAvailableVersion;              // Int to hold the new LCD FW version number
bool lcdVersionQueryFlag = false;                     // Flag to set if we've queried lcdVersion
const String lcdVersionQuery = "p[0].b[2].val";       // Object ID for lcdVersion in HMI
uint8_t lcdBacklightDim = 0;                          // Backlight dimmer value
bool lcdBacklightOn = 0;                              // Backlight on/off
bool lcdBacklightQueryFlag = false;                   // Flag to set if we've queried lcdBacklightDim
bool startupCompleteFlag = false;                     // Startup process has completed
const unsigned long statusUpdateInterval = 300000;    // Time in msec between publishing MQTT status updates (5 minutes)
unsigned long statusUpdateTimer = 0;                  // Timer for status update
const unsigned long connectTimeout = 300;             // Timeout for WiFi and MQTT connection attempts in seconds
const unsigned long reConnectTimeout = 60;            // Timeout for WiFi reconnection attempts in seconds
byte espMac[6];                                       // Byte array to store our MAC address
bool mqttTlsEnabled = false;                          // Enable MQTT client TLS connections
bool mqttPingCheck = false;                           // MQTT broker ping check result
bool mqttPortCheck = false;                           // MQTT broke port check result
String mqttClientId;                                  // Auto-generated MQTT ClientID
String mqttGetSubtopic;                               // MQTT subtopic for incoming commands requesting .val
String mqttStateTopic;                                // MQTT topic for outgoing panel interactions
String mqttStateJSONTopic;                            // MQTT topic for outgoing panel interactions in JSON format
String mqttCommandTopic;                              // MQTT topic for incoming panel commands
String mqttGroupCommandTopic;                         // MQTT topic for incoming group panel commands
String mqttStatusTopic;                               // MQTT topic for publishing device connectivity state
String mqttSensorTopic;                               // MQTT topic for publishing device information in JSON format
String mqttLightCommandTopic;                         // MQTT topic for incoming panel backlight on/off commands
String mqttLightStateTopic;                           // MQTT topic for outgoing panel backlight on/off state
String mqttLightBrightCommandTopic;                   // MQTT topic for incoming panel backlight dimmer commands
String mqttLightBrightStateTopic;                     // MQTT topic for outgoing panel backlight dimmer state
String mqttMotionStateTopic;                          // MQTT topic for outgoing motion sensor state
String mqttUpdateEspStateTopic;                       // MQTT topic for ESP update entity state
String mqttUpdateEspCommandTopic;                     // MQTT topic for ESP update entity install command
String mqttUpdateLcdStateTopic;                       // MQTT topic for LCD update entity state
String mqttUpdateLcdCommandTopic;                     // MQTT topic for LCD update entity install command
String nextionModel;                                  // Record reported model number of LCD panel
const byte nextionSuffix[] = {0xFF, 0xFF, 0xFF};      // Standard suffix for Nextion commands
uint8_t nextionMaxPages = 11;                         // Maximum number of pages in Nextion project
uint32_t tftFileSize = 0;                             // Filesize for TFT firmware upload
const uint8_t nextionResetPin = D6;                   // Pin for Nextion power rail switch (GPIO12/D6)
const unsigned long nextionSpeeds[] = {2400,
                                       4800,
                                       9600,
                                       19200,
                                       31250,
                                       38400,
                                       57600,
                                       115200,
                                       230400,
                                       250000,
                                       256000,
                                       512000,
                                       921600};                                       // Valid serial speeds for Nextion communication
const uint8_t nextionSpeedsLength = sizeof(nextionSpeeds) / sizeof(nextionSpeeds[0]); // Size of our list of speeds

WiFiClientSecure mqttClientSecure;        // TLS-enabled WiFiClient for MQTT
WiFiClient wifiClient;                    // Standard WiFiClient
MQTTClient mqttClient(mqttMaxPacketSize); // MQTT client
ESP8266WebServer webServer(80);           // Admin web server on port 80
ESP8266HTTPUpdateServer httpOTAUpdate;    // Arduino OTA server
WiFiServer telnetServer(23);              // Telnet server (if enabled)
WiFiClient telnetClient;                  // Telnet client
MDNSResponder::hMDNSService hMDNSService; // mDNS
EspSaveCrash SaveCrash;                   // Save crash details to flash

// URL for auto-update check of "version.json"
const char UPDATE_URL[] PROGMEM = "https://haswitchplate.com/update/version.json";
// Additional CSS style to match Hass theme
const char HASP_STYLE[] PROGMEM = "<style>button{background-color:#03A9F4;}body{width:60%;margin:auto;}input:invalid{border:1px solid red;}input[type=checkbox]{width:20px;}.wrap{text-align:left;display:inline-block;min-width:260px;max-width:1000px}</style>";
// Default link to compiled Arduino firmware image
String espFirmwareUrl = "http://haswitchplate.com/update/HASwitchPlate.ino.d1_mini.bin";
// Default link to compiled Nextion firmware images
String lcdFirmwareUrl = "http://haswitchplate.com/update/HASwitchPlate.tft";
// Release notes URLs populated from version.json
String espReleaseUrl = "https://github.com/HASwitchPlate/HASPone/releases/latest";
String lcdReleaseUrl = "https://github.com/HASwitchPlate/HASPone/releases/latest";

void setup();
void loop();
void mqttConnect();
void mqttProcessInput(String &strTopic, String &strPayload);
void mqttStatusUpdate();
void mqttUpdateState();
void mqttDiscovery();
void nextionHandleInput();
void nextionProcessInput();
void nextionSendCmd(const String &nextionCmd);
void nextionSetAttr(const String &hmiAttribute, const String &hmiValue);
void nextionGetAttr(const String &hmiAttribute);
void nextionParseJson(const String &strPayload);
void nextionOtaStartDownload(const String &lcdOtaUrl);
bool nextionOtaResponse();
bool nextionConnect();
void nextionSetSpeed();
void nextionReset();
void nextionUpdateProgress(const unsigned int &progress, const unsigned int &total);
void espWifiConnect();
void espWifiReconnect();
void espSetupOta();
void espStartOta(const String &espOtaUrl);
void espReset();
void configRead();
void configSaveCallback();
void configSave();
void configClearSaved();
void webHandleNotFound();
void webHandleRoot();
void webHandleSaveConfig();
void webHandleResetConfig();
void webHandleShowConfig();
void webHandleResetBacklight();
void webHandleFirmware();
void webHandleEspFirmware();
void webHandleLcdUpload();
void webHandleLcdUpdateSuccess();
void webHandleLcdUpdateFailure();
void webHandleLcdDownload();
void webHandleTftFileSize();
void webHandleReboot();
void espWifiConfigCallback(WiFiManager *myWiFiManager);
bool updateCheck();
void motionSetup();
void motionHandle();
void beepHandle();
void telnetHandleClient();
void debugPrintln(const String &debugText);
void debugPrint(const String &debugText);
void debugPrintCrash();
void debugPrintFile(const String &fileName);
String getSubtringField(String data, char separator, int index);
String printHex8(byte *data, uint8_t length);
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
void loop()
{ // Main execution loop
  while ((WiFi.status() != WL_CONNECTED) || (WiFi.localIP().toString() == "0.0.0.0"))
  { // Check WiFi is connected and that we have a valid IP, retry until we do.
    if (WiFi.status() == WL_CONNECTED)
    { // If we're currently connected, disconnect so we can try again
      WiFi.disconnect();
    }
    espWifiReconnect();
  }

  if (!mqttClient.connected())
  { // Check MQTT connection
    debugPrintln(String(F("MQTT: not connected, connecting.")));
    mqttConnect();
  }
  nextionHandleInput();     // Nextion serial communications loop
  mqttClient.loop();        // MQTT client loop
  ArduinoOTA.handle();      // Arduino OTA loop
  webServer.handleClient(); // webServer loop
  telnetHandleClient();     // telnet client loop
  motionHandle();           // motion sensor loop
  beepHandle();             // beep feedback loop

  if (mdnsEnabled)
  {
    MDNS.update();
  }

  if ((millis() - statusUpdateTimer) >= statusUpdateInterval)
  { // Run periodic status update
    statusUpdateTimer = millis();
    mqttStatusUpdate();
  }

  if (((millis() - updateCheckTimer) >= updateCheckInterval) && (millis() > updateCheckFirstRun))
  { // Run periodic update check
    updateCheckTimer = millis();
    if (updateCheck())
    { // Publish new status if updateCheck() worked and reset the timer
      statusUpdateTimer = millis();
      mqttStatusUpdate();
      mqttUpdateState();
    }
  }
}

////////////////////////////////////////////////////////////////////////////////////////////////////
// Functions

////////////////////////////////////////////////////////////////////////////////////////////////////
void mqttConnect()
{ // MQTT connection and subscriptions

  static bool mqttFirstConnect = true; // For the first connection, we want to send an OFF/ON state to
                                       // trigger any automations, but skip that if we reconnect while
                                       // still running the sketch
  rebootOnp0b1 = true;
  static uint8_t mqttReconnectCount = 0;
  unsigned long mqttConnectTimer = 0;
  const unsigned long mqttConnectTimeout = 5000;

  // Check to see if we have a broker configured and notify the user if not
  if (strcmp(mqttServer, "") == 0)
  {
    nextionSendCmd("page 0");
    nextionSetAttr("p[0].b[1].font", "6");
    nextionSetAttr("p[0].b[1].txt", "\"WiFi Connected!\\r " + String(WiFi.SSID()) + "\\rIP: " + WiFi.localIP().toString() + "\\r\\rConfigure MQTT:\\rhttp://" + WiFi.localIP().toString() + "\"");
    while (strcmp(mqttServer, "") == 0)
    { // Handle other stuff while we're waiting for MQTT to be configured
      yield();
      nextionHandleInput();     // Nextion serial communications loop
      ArduinoOTA.handle();      // Arduino OTA loop
      webServer.handleClient(); // webServer loop
      telnetHandleClient();     // telnet client loop
      motionHandle();           // motion sensor loop
      beepHandle();             // beep feedback loop
    }
  }

  if (mqttTlsEnabled)
  { // Create MQTT service object with TLS connection
    mqttClient.begin(mqttServer, atoi(mqttPort), mqttClientSecure);
    if (strcmp(mqttFingerprint, "") == 0)
    {
      debugPrintln(String(F("MQTT: Configuring MQTT TLS connection without fingerprint validation.")));
      mqttClientSecure.setInsecure();
    }
    else
    {
      debugPrintln(String(F("MQTT: Configuring MQTT TLS connection with fingerprint validation.")));
      mqttClientSecure.allowSelfSignedCerts();
      mqttClientSecure.setFingerprint(mqttFingerprint);
    }
    mqttClientSecure.setBufferSizes(512, 512);
  }
  else
  { // Create MQTT service object without TLS connection
    debugPrintln(String(F("MQTT: Configuring MQTT connection without TLS.")));
    mqttClient.begin(mqttServer, atoi(mqttPort), wifiClient);
  }

  mqttClient.onMessage(mqttProcessInput); // Setup MQTT callback function

  // MQTT topic string definitions
  mqttStateTopic = "hasp/" + String(haspNode) + "/state";
  mqttStateJSONTopic = "hasp/" + String(haspNode) + "/state/json";
  mqttCommandTopic = "hasp/" + String(haspNode) + "/command";
  mqttGroupCommandTopic = "hasp/" + String(groupName) + "/command";
  mqttStatusTopic = "hasp/" + String(haspNode) + "/status";
  mqttSensorTopic = "hasp/" + String(haspNode) + "/sensor";
  mqttLightCommandTopic = "hasp/" + String(haspNode) + "/light/switch";
  mqttLightStateTopic = "hasp/" + String(haspNode) + "/light/state";
  mqttLightBrightCommandTopic = "hasp/" + String(haspNode) + "/brightness/set";
  mqttLightBrightStateTopic = "hasp/" + String(haspNode) + "/brightness/state";
  mqttMotionStateTopic = "hasp/" + String(haspNode) + "/motion/state";
  mqttUpdateEspStateTopic = "hasp/" + String(haspNode) + "/update/esp";
  mqttUpdateEspCommandTopic = "hasp/" + String(haspNode) + "/update/esp/install";
  mqttUpdateLcdStateTopic = "hasp/" + String(haspNode) + "/update/lcd";
  mqttUpdateLcdCommandTopic = "hasp/" + String(haspNode) + "/update/lcd/install";

  const String mqttCommandSubscription = mqttCommandTopic + "/#";
  const String mqttGroupCommandSubscription = mqttGroupCommandTopic + "/#";
  const String mqttLightSubscription = mqttLightCommandTopic + "/#";
  const String mqttLightBrightSubscription = mqttLightBrightCommandTopic + "/#";

  // Generate an MQTT client ID as haspNode + our MAC address
  mqttClientId = String(haspNode) + "-" + String(espMac[0], HEX) + String(espMac[1], HEX) + String(espMac[2], HEX) + String(espMac[3], HEX) + String(espMac[4], HEX) + String(espMac[5], HEX);
  nextionSendCmd("page 0");
  nextionSetAttr("p[0].b[1].font", "6");
  nextionSetAttr("p[0].b[1].txt", "\"WiFi Connected!\\r " + String(WiFi.SSID()) + "\\rIP: " + WiFi.localIP().toString() + "\\r\\rMQTT Connecting:\\r " + String(mqttServer) + "\"");
  if (mqttTlsEnabled)
  {
    debugPrintln(String(F("MQTT: Attempting connection to broker ")) + String(mqttServer) + String(F(" on port ")) + String(mqttPort) + String(F(" with TLS enabled as clientID ")) + mqttClientId);
  }
  else
  {
    debugPrintln(String(F("MQTT: Attempting connection to broker ")) + String(mqttServer) + String(F(" on port ")) + String(mqttPort) + String(F(" with TLS disabled as clientID ")) + mqttClientId);
  }

  // Set keepAlive, cleanSession, timeout
  mqttClient.setOptions(30, true, mqttConnectTimeout);

  // declare LWT
  mqttClient.setWill(mqttStatusTopic.c_str(), "OFF", true, 1);

  while (!mqttClient.connected())
  { // Loop until we're connected to MQTT
    mqttConnectTimer = millis();
    mqttClient.connect(mqttClientId.c_str(), mqttUser, mqttPassword, false);

    if (mqttClient.connected())
    { // Attempt to connect to broker, setting last will and testament
      // Update panel with MQTT status
      nextionSetAttr("p[0].b[1].txt", "\"WiFi Connected!\\r " + String(WiFi.SSID()) + "\\rIP: " + WiFi.localIP().toString() + "\\r\\rMQTT Connected:\\r " + String(mqttServer) + "\"");
      debugPrintln(F("MQTT: connected"));

      // Reset our diagnostic booleans
      mqttPingCheck = true;
      mqttPortCheck = true;

      // Subscribe to our incoming topics
      if (mqttClient.subscribe(mqttCommandSubscription))
      {
        debugPrintln(String(F("MQTT: subscribed to ")) + mqttCommandSubscription);
      }
      if (mqttClient.subscribe(mqttGroupCommandSubscription))
      {
        debugPrintln(String(F("MQTT: subscribed to ")) + mqttGroupCommandSubscription);
      }
      if (mqttClient.subscribe(mqttLightSubscription))
      {
        debugPrintln(String(F("MQTT: subscribed to ")) + mqttLightSubscription);
      }
      if (mqttClient.subscribe(mqttLightBrightSubscription))
      {
        debugPrintln(String(F("MQTT: subscribed to ")) + mqttLightBrightSubscription);
      }
      if (mqttClient.subscribe(mqttUpdateEspCommandTopic))
      {
        debugPrintln(String(F("MQTT: subscribed to ")) + mqttUpdateEspCommandTopic);
      }
      if (mqttClient.subscribe(mqttUpdateLcdCommandTopic))
      {
        debugPrintln(String(F("MQTT: subscribed to ")) + mqttUpdateLcdCommandTopic);
      }

      // Publish discovery configuration
      mqttDiscovery();

      // Publish update entity state
      mqttUpdateState();
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

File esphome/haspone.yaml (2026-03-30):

# Example ESPhome configuration for use with the HASPone hardware
#
# NOTE ON UART: The HASPone PCB connects the Nextion to GPIO2 (TX) and GPIO13 (RX).
# These pins span two different hardware UARTs (UART1 TX-only and UART0-swapped RX),
# so ESPHome must use SoftwareSerial here. The Arduino firmware works around this by
# using Serial1 for TX and Serial.swap() for RX independently - a trick ESPHome's
# Nextion component cannot replicate since it requires a single UART instance.
#
# TFT updates over SoftwareSerial may be unreliable at high baud rates. For Nextion
# firmware flashing, use the Nextion Editor with a USB-TTL adapter directly, or use
# the Arduino firmware's built-in OTA update mechanism.
#
# Logging is sent over the network (API + web_server) rather than USB serial, since
# UART0 default pins (GPIO1/GPIO3) conflict with the Nextion after boot.

substitutions:
  device_name: "haspone"
  friendly_name: "HASPone hardware for ESPhome"
  project_version: "0.0.2"

esphome:
  name: ${device_name}
  friendly_name: ${friendly_name}
  comment: "http://haswitchplate.com"
  project:
    name: "esphome.${device_name}"
    version: ${project_version}
  on_boot:
    then:
    - switch.turn_on: switch_lcdpower # Power up the Nextion on boot

esp8266:
  board: d1_mini

# Disable serial logging - UART0 default pins conflict with Nextion,
# and there's no spare hardware UART for USB output.
# Logs are available via the web UI (http://<device-ip>) and ESPHome dashboard (API).
logger:
  baud_rate: 0

api:

ota:
  - platform: esphome

wifi:
  ssid: !secret wifi_ssid
  password: !secret wifi_password

# Web UI provides device logs, controls, and status at http://<device-ip>
web_server:
  port: 80

# HASPone switch controls power to the Nextion via a MOSFET on the PCB.
switch:
  - platform: gpio
    id: switch_lcdpower
    name: "${friendly_name} Nextion Power"
    pin: D6 #GPIO12
    restore_mode: ALWAYS_ON
    internal: false

# UART for Nextion communication.
# GPIO2 (UART1 HW TX) + GPIO13 (UART0-swapped HW RX) = SoftwareSerial in ESPHome.
# 115200 is the most reliable baud rate for SoftwareSerial on ESP8266.
uart:
  id: uart_nextion
  tx_pin: D4 #GPIO2
  rx_pin: D7 #GPIO13
  baud_rate: 115200

# Nextion display device
display:
  - platform: nextion
    id: display_nextion
    uart_id: uart_nextion
    on_touch:
      then:
        lambda: |-
          ESP_LOGD("nextion.on_touch", "Nextion touch event detected!");
          ESP_LOGD("nextion.on_touch", "Page Id: %i", page_id);
          ESP_LOGD("nextion.on_touch", "Component Id: %i", component_id);
          ESP_LOGD("nextion.on_touch", "Event type: %s", touch_event ? "Press" : "Release");

# Nextion backlight control
number:
  - platform: template
    id: number_brightness
    name: "${friendly_name} Nextion Brightness"
    min_value: 0
    max_value: 100
    step: 1
    initial_value: 100
    optimistic: true
    set_action:
      - lambda: id(display_nextion)->set_backlight_brightness(x/100);

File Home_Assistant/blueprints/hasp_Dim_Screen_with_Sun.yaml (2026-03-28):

blueprint:
  name: "HASPone dims the backlight with the sun"
  description: |

    ## Blueprint Version: `1.08.00`

    # Description

    Dim the HASPone backlight in response to the sun going up and down.

  domain: automation
  input:
    haspdevice:
      name: "HASPone Device"
      description: "Select the HASPone device"
      selector:
        device:
          integration: mqtt
          manufacturer: "HASwitchPlate"
          model: "HASPone v1.0.0"
    brightday:
      name: "Daytime brightness value"
      description: "Select the brightness value to be set during full daylight."
      default: 100
      selector:
        number:
          min: 1
          max: 100
          mode: slider
          unit_of_measurement: "%"
    brightnight:
      name: "Nighttime brightness value"
      description: "Select the brightness value to be set during the night."
      default: 5
      selector:
        number:
          min: 0
          max: 100
          mode: slider
          unit_of_measurement: "%"
    elevationday:
      name: "Daytime sun elevation"
      description: "Sun elevation to begin transition at night and to end transition in the morning.  Value must be greater than the nighttime elevation set below."
      default: 6
      selector:
        number:
          min: -90
          max: 90
          step: 1
          mode: slider
          unit_of_measurement: "°"
    elevationnight:
      name: "Nighttime sun elevation"
      description: "Sun elevation to end transition at night and to begin transition in the morning.  Value must be less than the daytime elevation set above."
      default: -6
      selector:
        number:
          min: -90
          max: 90
          step: 1
          mode: slider
          unit_of_measurement: "°"

mode: parallel
max_exceeded: silent

variables:
  haspdevice: !input haspdevice
  haspname: >-
    {%- for entity in device_entities(haspdevice) -%}
      {%- if entity|regex_search("^sensor\..+_sensor(?:_\d+|)$") -%}
        {{- entity|regex_replace(find="^sensor\.", replace="", ignorecase=true)|regex_replace(find="_sensor(?:_\d+|)$", replace="", ignorecase=true) -}}
      {%- endif -%}
    {%- endfor -%}
  haspsensor: >-
    {%- for entity in device_entities(haspdevice) -%}
      {%- if entity|regex_search("^sensor\..+_sensor(?:_\d+|)$") -%}
        {{ entity }}
      {%- endif -%}
    {%- endfor -%}
  brightday: !input brightday
  brightnight: !input brightnight
  elevationday: !input elevationday
  elevationnight: !input elevationnight
  lightcommandtopic: "{{ 'hasp/' ~ haspname ~ '/brightness/set' }}"

trigger:
  - trigger: state
    entity_id: sun.sun
    attribute: elevation

condition:
  - condition: template
    value_template: "{{ is_state(haspsensor, 'ON') }}"
  - condition: template
    value_template: "{{ state_attr('sun.sun', 'elevation') | round(default=90) <= elevationday }}"
  - condition: template
    value_template: "{{ state_attr('sun.sun', 'elevation') | round(default=-90) >= elevationnight }}"

action:
  - choose:
      #########################################################################
      # Sun elevation is approximately equal to or greater than daytime value, send brightday
      - conditions:
          - condition: template
            value_template: "{{ state_attr('sun.sun', 'elevation') | round(default=0) >= elevationday }}"
        sequence:
          - service: mqtt.publish
            data:
              topic: "{{ lightcommandtopic }}"
              payload: "{{ brightday | int }}"
      #########################################################################
      # Sun elevation is approximately equal to or less than nighttime value, send brightnight
      - conditions:
          - condition: template
            value_template: "{{ state_attr('sun.sun', 'elevation') | round(default=0) <= elevationnight }}"
        sequence:
          - service: mqtt.publish
            data:
              topic: "{{ lightcommandtopic }}"
              payload: "{{ brightnight | int }}"
    #########################################################################
    # Sun elevation is in transition range, send calculated brightness value
    default:
      - service: mqtt.publish
        data:
          topic: "{{ lightcommandtopic }}"
          payload: "{{ (brightnight + ((brightday - brightnight) / (elevationday - elevationnight)) * (state_attr('sun.sun', 'elevation') - elevationnight)) | round(default=0) | int }}"

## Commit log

2021-03-05 Add ability to round off temperature values
2021-03-06 trigger activate page on button release
2021-03-06 Fix error introduced in button release event
2021-03-07 Fix hardcoded device name
2021-03-15 Change default blueprint name
    Remove '.b[y]' and add '.sec[x]' to the name because the automation doesn't apply to a button, but references a second/time.
    I thought about if this should be 's' or 'sec', but concluded that 's' was too like 'b' - both being single letters - and so sec better reflected the default information that should go there.
2021-03-19 Automation to dim the screen after idle timeout
    Cribbed from the change-page-on-idle automation, this one alters the
    screen brightness (using MQTT, not the Home-Assistant Concept of
    Backlight).
    the value of "dim" and "bright" can be set, and so can the timeout.
    Drawbacks: now every button_short_press causes a brightness change
    command to be sent. And this doesn't honour the Home-Assistant
    Concept of Backlight slider, which is not intuitive and could be
    done better.
    Do sliders generate button_short_press events?
2021-03-19 control a climate.heatpump on page9 with teeny buttons
2021-03-19 adapt page9 Heatpump controls to page6
2021-03-19 Icon-only version of the Weather Condition
    Forked the weather-condition-with-icon blueprint, which
    has a right-aligned text description of the weather and a super-magic
    overstrike icon left-aligned of the weather condition.
    Removed the text field entirely, so we get the same icons for the
    same conditions, but centred.
    Suitable for use on small buttons to convey at a glance approximately
    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
2021-03-19 Icon-only version of Temperature Display
    Forked the temperature-with-colour-icon blueprint, which
    has a right-aligned text description of the temperature and a
    super-magic overstrike icon left-aligned of a thermometer.
    Removed the text field entirely, so we get an optionally coloured
    thermometer that changes height with the temperature, but centred
    what the mercury is doing
    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
2021-03-20 Added single-gang-large switchplate stl
    Larger single-gange switchplate (1/2" larger in both dimensions)
    [HASwitchPlate_front_single_large.stl]
2021-04-02 Test binary w/ ESP8266 Arduino 3.0pre
2021-04-25 Send page button color config on RUN ACTIONS
2021-05-02 unscrewup git screwup
2021-06-23 Candidate fix for issue 106 and Heatpump page 6
    Remove hp_is_off and toggle_hp_state from page6 entirely
    Remove hp_is_off and toggle_hp_state from page9 triggers
    Should remove the warnings that were tripping the upstream issue 106:
    https://github.com/HASwitchPlate/HASPone/issues/106
2021-06-27 Align button disabled events with project
2021-07-05 Update alarm blueprint to allow multiple arm services
2021-07-06 Resolve issue w/ JSON value return button IDs
2021-07-06 Add current 1.03 firmware binary to dev branch
2021-07-29 Add rear enclosed model for desktop
    [HASwitchPlate_desktop_rear_enclosed.stl]
2021-08-08 Revert weather temp display to only support weather entities
    [hasp_Dim_Screen_with_Sun.yaml]
2021-11-10 Provide default for filters for 2021.12, add ad-hoc version
2021-11-27 Update branding, fix sensor identification templates
    [hasp_Dim_Screen_with_Sun.yaml]
2022-02-24 Add -deep front single model
    [HASwitchPlate_front_single_deep.stl]
2022-04-18 New models
    [HASwitchPlate_front_4x_hasp_decora_decora_decora.stl]
2022-04-18 compiled snapshot of current dev build
2022-04-19 add defaults to template filters, fix page 2 colors in scroll mode
2022-09-06 Add new models, update binary with latest libraries
    [HASwitchPlate_front_2x_decora_hasp.stl, HASwitchPlate_front_2x_hasp_decora.stl, HASwitchPlate_front_2x_hasp_toggle.stl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]
2023-02-21 Update ESP8266 to latest SDK and Arduino build
2023-11-02 Update doc images
    [HASwitchPlate_front_3x_decora_decora_hasp.stl]
2023-12-26 New MQTT discovery style, revert to old update server
    [HASwitchPlate.cpp]
2023-12-27 fix lcd update message, faster update check
    [HASwitchPlate.cpp]
2024-04-28 Add 4in box model
    [HASwitchPlate_front_4in_box.stl]
2026-03-28 Add a configurable rebootOnLongPressTimeout and fixed the warning caused by DynamicJsonDocument
    [HASwitchPlate.cpp]
2026-03-28 Replaced object_id with default_entity_id as mentioned in warning startups to prevent breaking changes when 2026.4 is releaaed.
    [HASwitchPlate.cpp]
2026-03-28 Address logic errors uncovered by Claude
    [HASwitchPlate.cpp]
2026-03-28 1.09 arduino binaries
2026-03-29 Fix remote updates with CF worker
    [HASwitchPlate.cpp]
